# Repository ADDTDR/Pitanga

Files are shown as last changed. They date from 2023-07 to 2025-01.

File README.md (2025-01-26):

# Pitanga Project

Prototype 0.01            |  Pitanga V1 |  Pitanga V2.1a
:-------------------------:|:-------------------------:|:-------------------------:
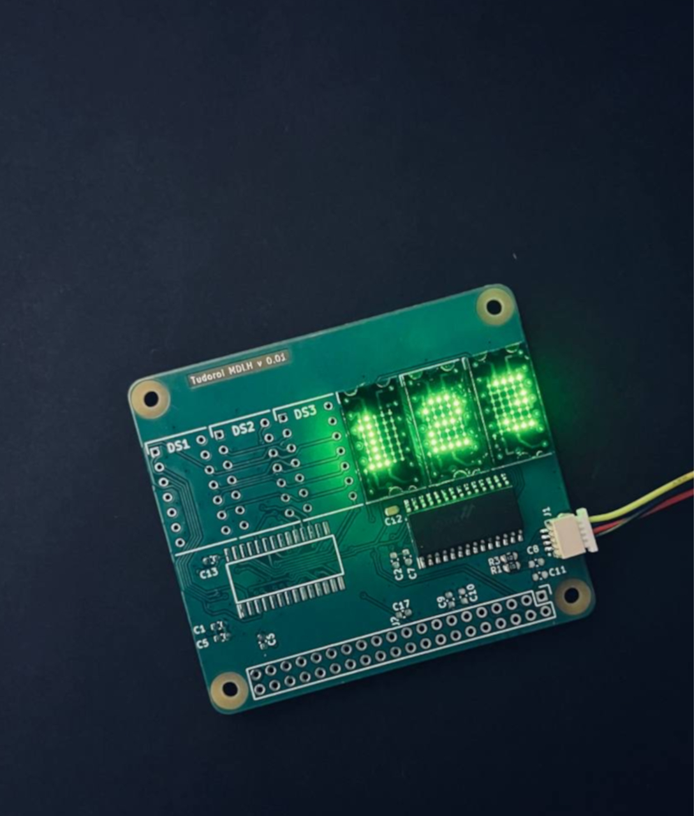
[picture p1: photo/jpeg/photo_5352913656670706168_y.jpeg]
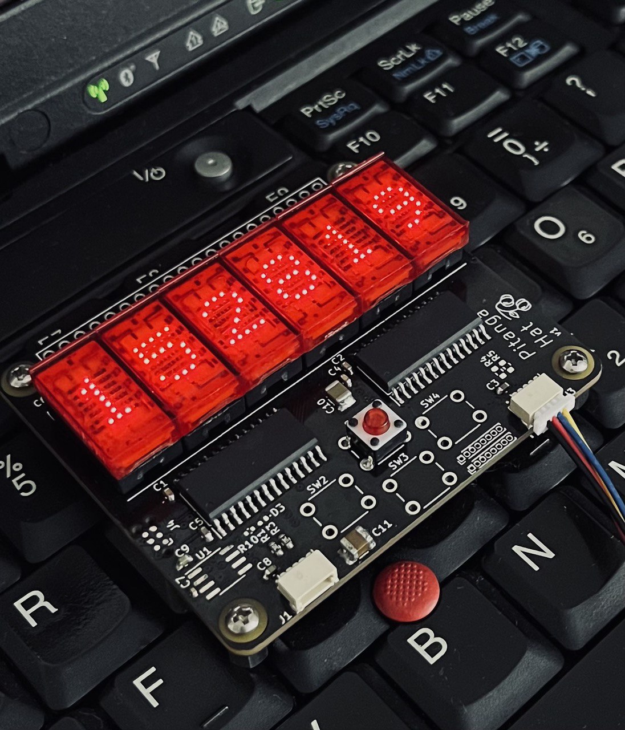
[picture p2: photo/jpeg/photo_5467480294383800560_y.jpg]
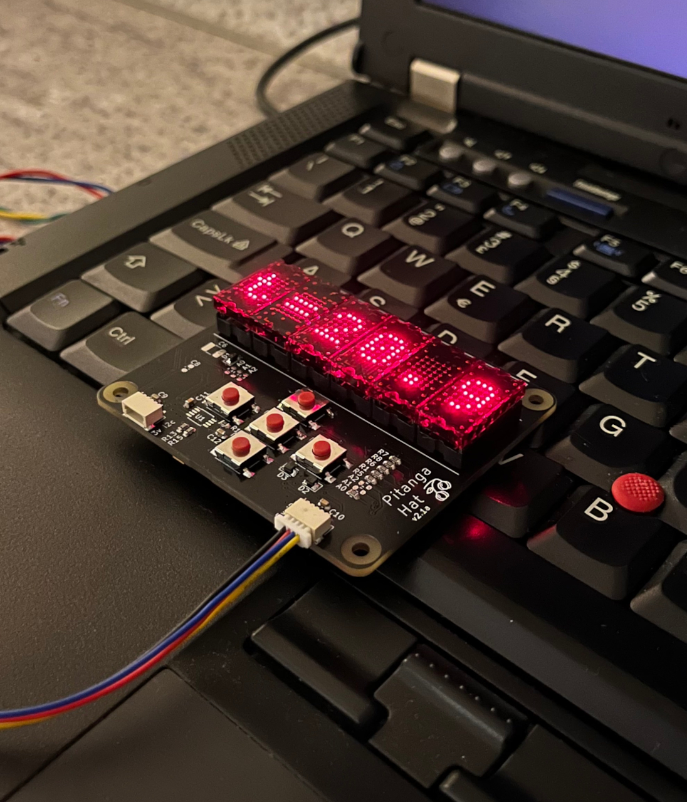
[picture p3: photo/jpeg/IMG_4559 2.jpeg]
  |    | 

<!-- # Prototype A 
```LTP-305G```
![Alt text](photo/jpeg/photo_5352913656670706168_y.jpeg)
![Alt text](photo/jpeg/photo_5352913656670706159_y.jpeg) 
# First version 
```ALS340A1 installed``` 
![Alt text](<photo/jpeg/IMG_4408 2.jpeg>)
![Alt text](<photo/jpeg/IMG_4409 2.jpeg>)
![Alt text](<photo/jpeg/IMG_4431 2.jpeg>)
Als340A1 and ALS340A
![Alt text](<photo/jpeg/IMG_4410 2.jpeg>)
ALS340A, ALS230A1, LTP305R, LTP305G
![Alt text](<photo/jpeg/IMG_4414 2.jpeg>)
ALS340A1
![Alt text](<photo/jpeg/IMG_4426 2.jpeg>)
# Version 2.1a
```LTP 305R```
![Alt text](<photo/jpeg/IMG_4559 2.jpeg>) -->

## 3D
![alt text](PitangaBlender/render/render.gif)

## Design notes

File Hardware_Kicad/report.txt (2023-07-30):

Changed footprint DS1 from 'LTP-305G:DIPS762W50P254L1850H400Q14N' to 'LTP-305G:DIPS762W50P254L1850H400Q14N': : OK

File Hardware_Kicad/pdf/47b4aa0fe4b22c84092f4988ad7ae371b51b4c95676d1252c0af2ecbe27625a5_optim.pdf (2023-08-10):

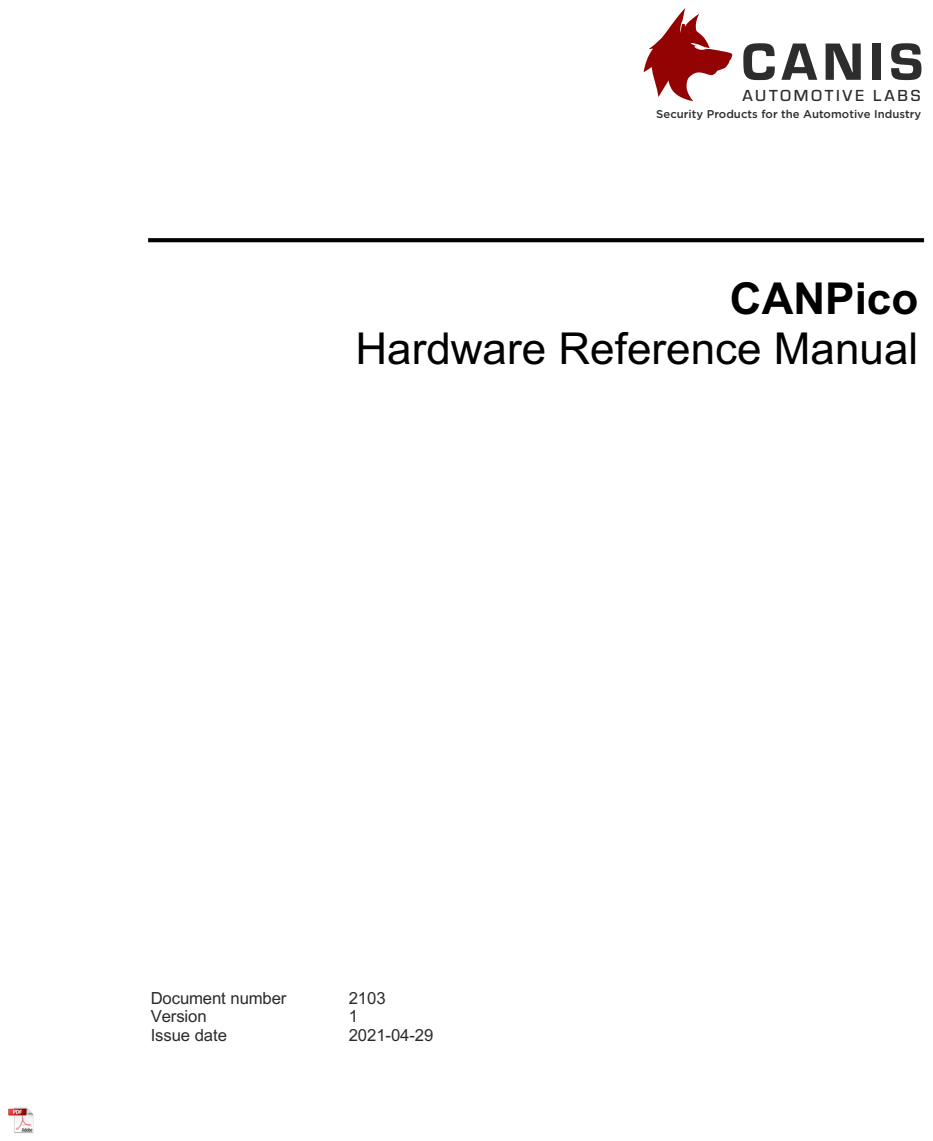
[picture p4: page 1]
CANIS; AUTOMOTIVE LABS; CANPico; Document number; Version; Issue date

Security Products for the Automotive Industry

Hardware Reference Manual

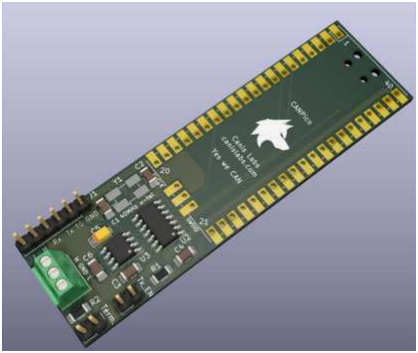
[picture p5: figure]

Copyright © 2021 Canis Automotive Labs Ltd. | 2 / 8

## 1 Introduction

The CANPico is a ‘sock’ board designed to connect a Raspberry Pi Pico board to a CAN bus. A Pico board is soldered down on to the upper area of the board and the lower area of the board contains the CAN connectors.

CAN bus is a protocol used in many applications, from trucks to buses to aircraft to agricultural equipment to medical devices to construction equipment and even spacecraft but its most common use is in cars.

WARNING. Connecting the CANPico directly to a vehicle CAN bus comes with risk and should not be undertaken without understanding this risk. Grounding a vehicle chassis through the USB port of a Pico connected to a laptop, PC or USB hub powered from the mains may cause permanent damage to the vehicle’s electronics and/or the Raspberry Pi Pico and devices it is connected to. The CAN transceiver will tolerate a ground potential difference (“ground offset”) of between -2V/+7V. Connecting pin 2 of the screw terminal to the target system’s ground will establish a common ground reference. The CAN bus must be properly terminated (with 120W resistors at either end). If the CAN bus is already terminated then the termination jumper on the CANPico should not be closed. In addition, causing disruption to a vehicle’s CAN bus traffic may be interpreted by the vehicle fault management systems as a hardware fault and cause the vehicle to permanently shut down CAN communications with consequent loss of functionality.

The CANPico has the following features:

- Microchip MCP2517/18FD CAN controller
- Microchip MCP2562FD CAN transceiver
- Jumper header to enable a 120W CAN bus termination resistor
- Jumper header to enable the CAN TX line to the transceiver¹
- Screw terminal connector to CAN bus
- CAN controller interrupt and Start-of-Frame inputs to GPIO pins
- Direct access via GPIO pins to the CAN transceiver TX and RX pins
- Test instrument header (for an oscilloscope or logic analyzer)

The features are described in more detail in the following sections. Appendix A contains the CANPico schematics.

1 Normally connected, removed to prevent software from transmitting on the CAN bus

## 2 CAN controller

The CAN controller used in the CANPico is the Microchip MCP2518FD (or in some cases the older MCP2517FD). The MCP2517/18FD is driven via SPI:

The CAN controller is clocked by a 40MHz crystal and the SPI clock from the RP2040 on the Pico can go up to 18.5MHz. More details on the SPI interface can be found in section 4 of the CAN controller datasheet (available from Microchip).

The controller can be programmed to generate an interrupt (level sensitive, active low) and this is routed to a GPIO pin on the Pico. In addition, a start-of-frame (SOF) signal is routed to another GPIO pin on the Pico, to allow timestamps in the controller for SOF to be correlated with a timer on the Pico (by latching a freerunning counter at the rising edge of the SOF signal).

The SOF signal is multiplexed with a clock signal and on power-on-reset the line is clocked at 4MHz until software re-purposes it to SOF.

## 3 CAN physical layer

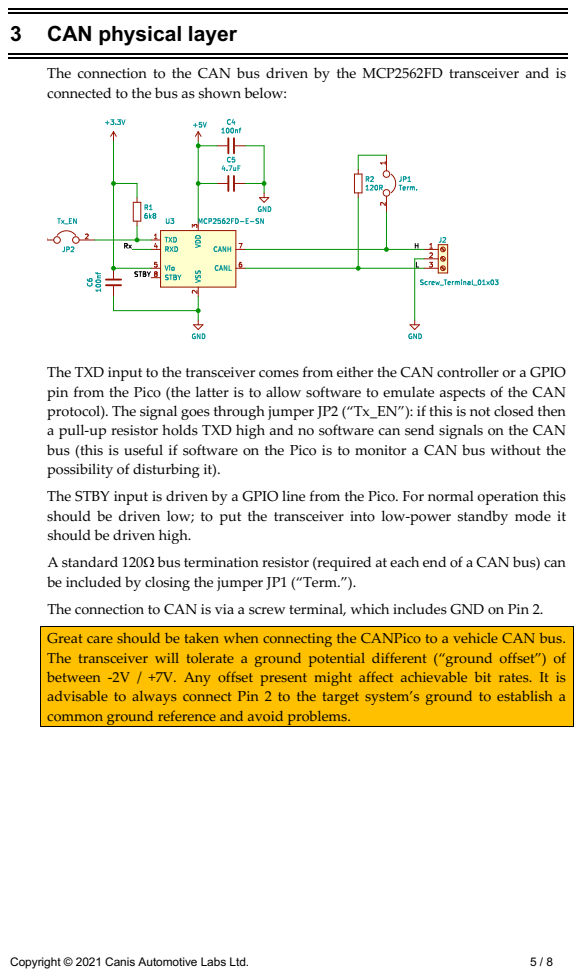
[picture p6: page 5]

The connection to the CAN bus driven by the MCP2562FD transceiver and is
connected to the bus as shown below:

The TXD input to the transceiver comes from either the CAN controller or a GPIO
pin from the Pico (the latter is to allow software to emulate aspects of the CAN
protocol). The signal goes through jumper JP2 (“Tx_EN”): if this is not closed then
a pull-up resistor holds TXD high and no software can send signals on the CAN
bus (this is useful if software on the Pico is to monitor a CAN bus without the
possibility of disturbing it).
The STBY input is driven by a GPIO line from the Pico. For normal operation this
should be driven low; to put the transceiver into low-power standby mode it
should be driven high.
A standard 120W bus termination resistor (required at each end of a CAN bus) can
be included by closing the jumper JP1 (“Term.”).
The connection to CAN is via a screw terminal, which includes GND on Pin 2.

Great care should be taken when connecting the CANPico to a vehicle CAN bus.
The transceiver will tolerate a ground potential different (“ground offset”) of
between -2V / +7V. Any offset present might affect achievable bit rates. It is
advisable to always connect Pin 2 to the target system’s ground to establish a
common ground reference and avoid problems.

## 4 Raspberry Pi Pico connections

The interface between the CANPico and the Raspberry Pi Pico is shown below:

The Pico should be soldered to the CANPico at the 13 pins shown in the schematic above. The Pico has castellated (“half moon”) edges to support this, allowing headers to be soldered into the holes if an additional Pico-compatible board is to be connected. The Pico SPI1 interface²
is used to connect to the CANPico, leaving SPI0 free to connect to other boards.

The TRIG pin (GPIO2) connects to the test instrument header. The intention is that software can be used to evaluate conditions (e.g. receiving a CAN frame with a specific ID or payload) that will trigger a logic analyzer or oscilloscope to show what was happening on the CAN line around the event.

The STBY pin (GPIO3) is used to switch the CAN transceiver between standby and normal mode.

The SOF pin (GPIO4) is wired to the CLK0/SOF pin of the CAN transceiver. On power-up this is a 4MHz clock until software re-purposes the input. If an edgesensitive SOF interrupt is required it will be important to initialize the CAN controller over SPI before enabling interrupts on GPIO4.

The Tx and Rx pins (GPIO22 and GPIO21) are wired to the CAN transceiver to allow direct software control (e.g. bit-banging the CAN protocol). This pin assignment is compatible with the CANHack pin assignment. If the Tx pin is driven by software then the CAN controller must be put into open drain mode output mode before the GPIO22 is enabled as an output (this prevents both the CAN controller and software directly driving the same line).

2 Note that the chip select pin CSn is to be driven by software (the hardware chip select included in the RP2040 SPI interface is not capable of driving the MCP2517/18FD SPI interface)

## 5 Test instrument header

A test instrument header is included to allow a logic analyzer and/or oscilloscope to monitor the CAN bus. The schematic for this header is shown below:

The TRIG pin is controlled from GPIO2 on the Pico. This can be driven by software to trigger a test instrument when certain conditions are observed. It can also be used as a general-purpose debugging pin (e.g. for measuring the execution time of sections code code).

The Rx pin is connected to the CAN transceiver’s RXD pin. Typically this would be an input to a logic analyzer monitoring the CAN bus.

The Tx pin is the output of the CAN controller and GPIO22.

The H and L pins are directly connected to CAN H and CAN L bus lines. Typically these would be inputs to an oscilloscope monitoring the CAN bus.

## 6 Appendix A: Schematics

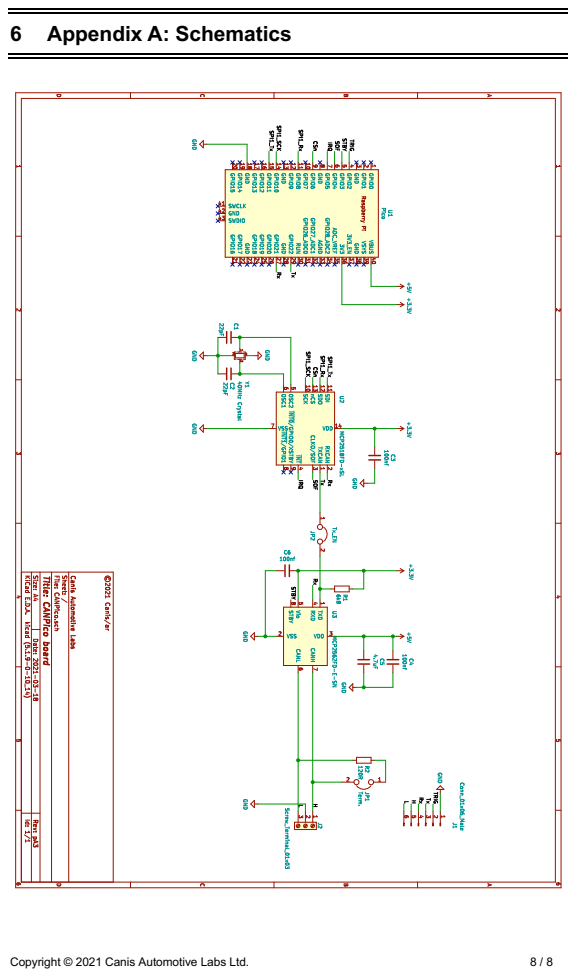
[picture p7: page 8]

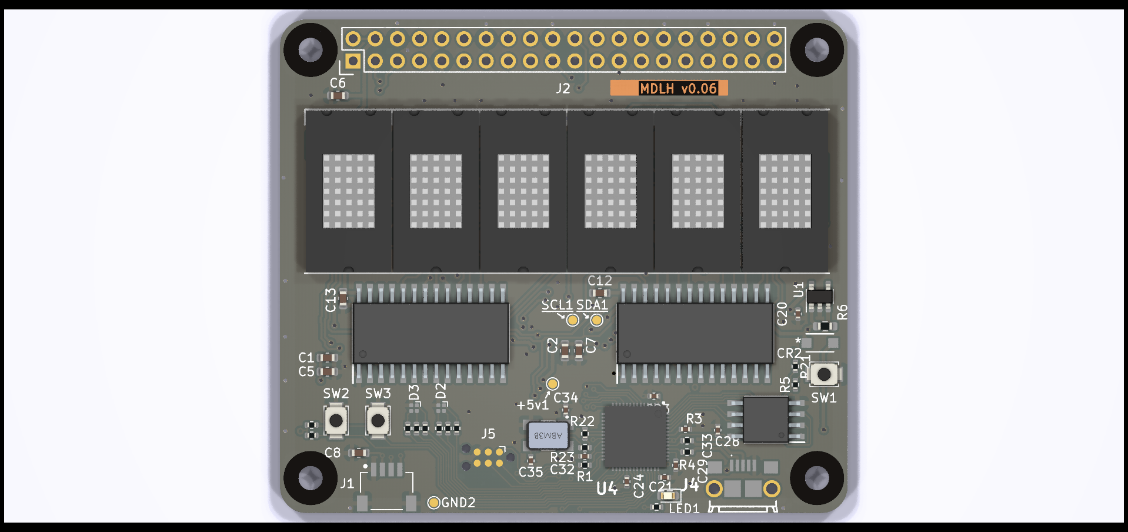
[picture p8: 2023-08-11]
Hardware_Kicad/render_images/ltp_kikad_f9.png

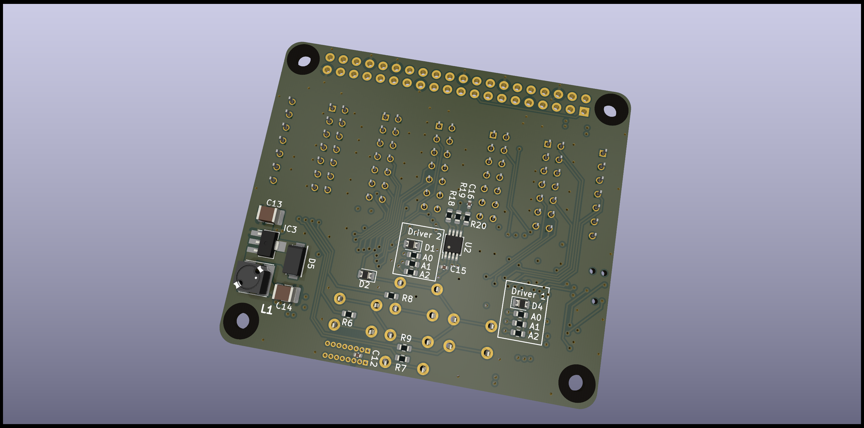
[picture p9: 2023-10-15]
Hardware_Kicad/render_images/Pitanga/pitanga_v1_back.png

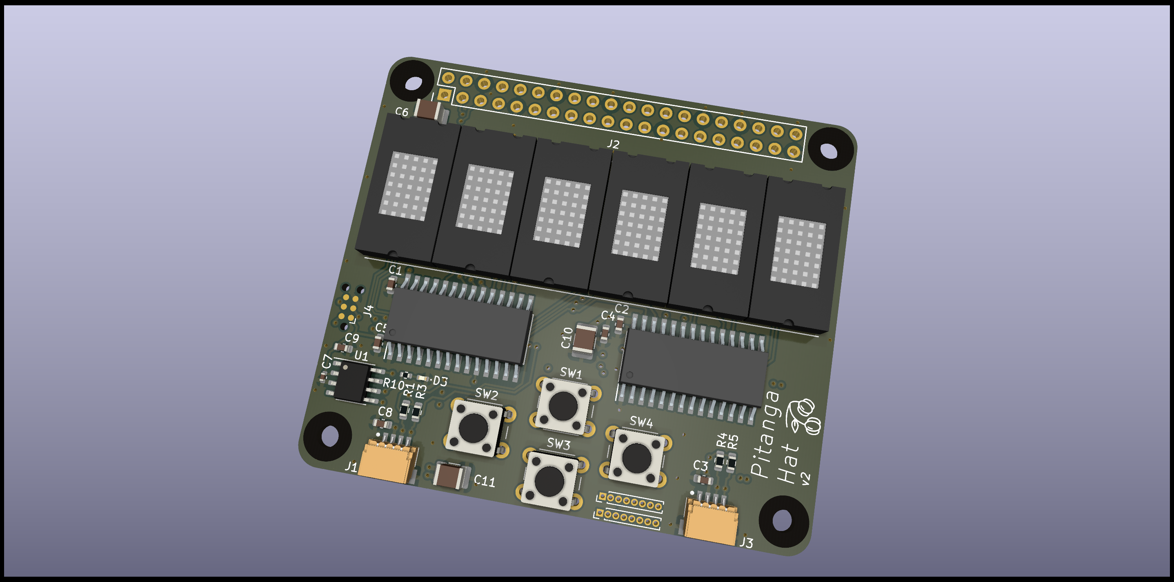
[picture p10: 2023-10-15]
Hardware_Kicad/render_images/Pitanga/pitanga_v1_front.png

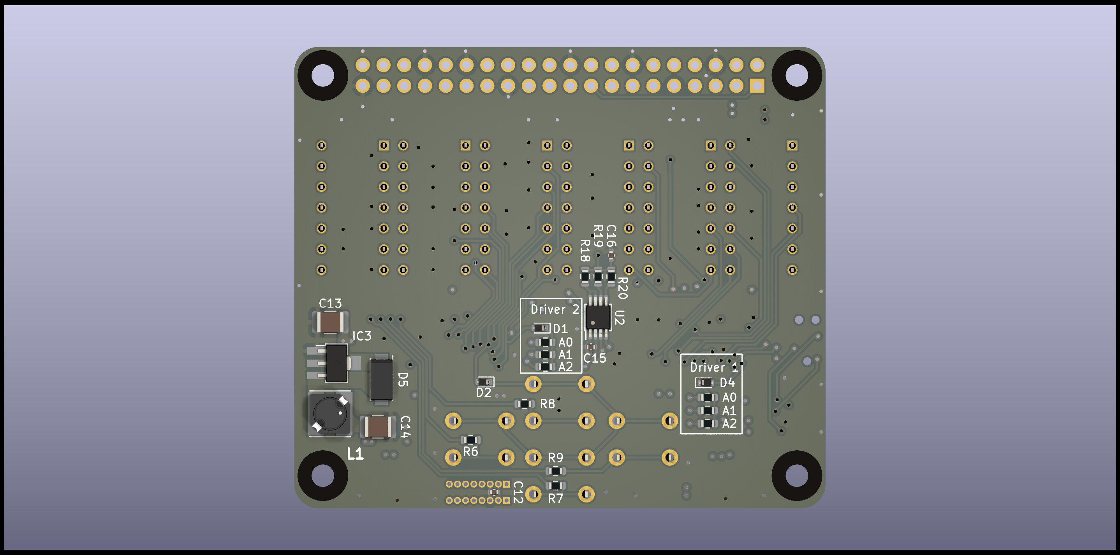
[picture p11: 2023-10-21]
Hardware_Kicad/render_images/Pitanga/pitanga_v2_back.png

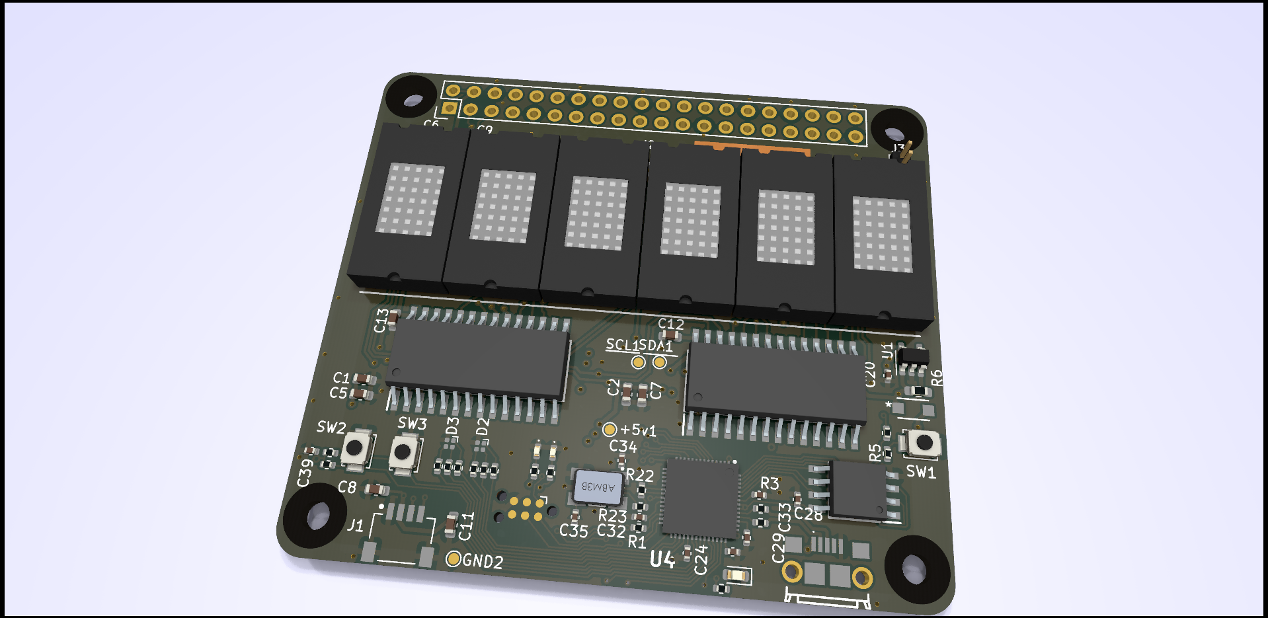
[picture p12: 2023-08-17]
Hardware_Kicad/render_images/ltp_kikad_f10.png

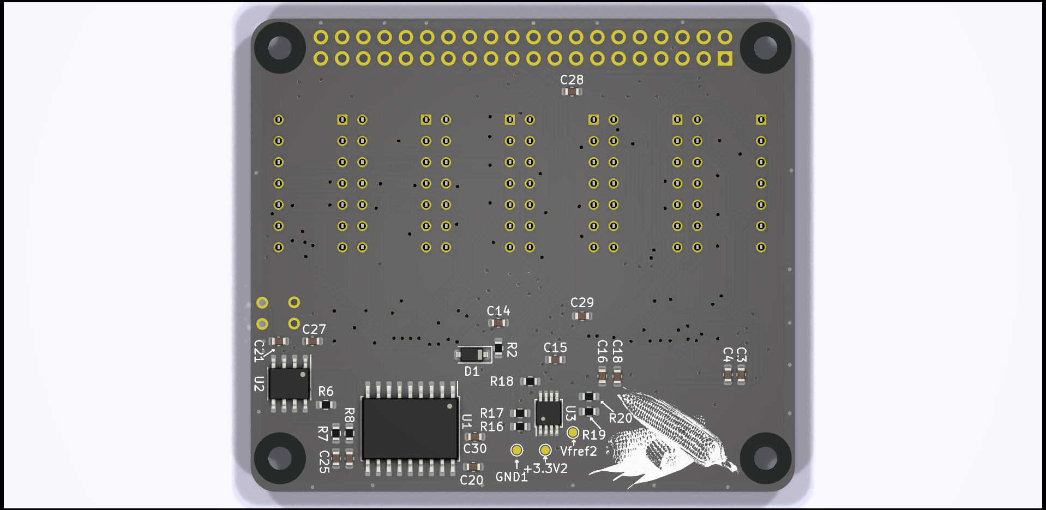
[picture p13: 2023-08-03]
Hardware_Kicad/render_images/ltp_kikad_6_b.png

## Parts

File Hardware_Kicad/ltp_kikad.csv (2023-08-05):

Source: | E:\ltp_kikad\ltp_kikad.kicad_sch
Date: | 8/4/2023 5:59:29 PM
Tool: | Eeschema 7.0.5
Generator: | C:\Program Files\KiCad\7.0\bin\scripting\plugins/bom_csv_grouped_by_value.py
Component Count: | 73
Collated Components:
Item | Qty | Reference(s) | Value | LibPart | Footprint | Datasheet | DNP | Arrow Part Number | Arrow Price/Stock | Description | Digi-Key_PN | Height | MANUFACTURER | MPN | Manufacturer | Manufacturer_Name | Manufacturer_Part_Number | Mouser Part Number | Mouser Price/Stock | STANDARD | Sim.Device | Sim.Pins
1 | 4 | +3.3v1, +5v1, GND1, GND2 | TestPoint | Connector:TestPoint | TestPoint:TestPoint_Pad_D1.0mm | ~
2 | 1 | +3.3V2 | TP3.3v | Connector:TestPoint | TestPoint:TestPoint_Pad_D1.0mm | ~
3 | 15 | C1, C2, C7, C8, C9, C10, C11, C12, C13, C14, C15, C16, C17, C18, C27 | 10uF | Device:C_Small | Capacitor_SMD:C_0603_1608Metric | ~
4 | 4 | C3, C4, C19, C22 | 4.7uF | Device:C_Small | Capacitor_SMD:C_0603_1608Metric | ~
5 | 7 | C5, C6, C20, C21, C28, C29, C30 | 0.1uF | Device:C_Small | Capacitor_SMD:C_0603_1608Metric | ~
6 | 2 | C23, C24 | 22pF | Device:C_Small | Capacitor_SMD:C_0603_1608Metric | ~
7 | 2 | C25, C26 | 560pF | Device:C_Small | Capacitor_SMD:C_0603_1608Metric | ~
8 | 1 | CAN1 | Jumper_2_Open | Jumper:Jumper_2_Open | TestPoint:TestPoint_2Pads_Pitch2.54mm_Drill0.8mm | ~
9 | 1 | D1 | 1N4148 | Device:D | Diode_SMD:D_SOD-123 | ~ |  |  |  |  |  |  |  |  |  |  |  |  |  |  | D | 1=K 2=A
10 | 6 | DS1, DS2, DS3, DS4, DS5, DS6 | LTP-305G | LTP-305G:LTP-305G | LTP-305G:DIPS762W50P254L1850H400Q14N | https://media.digikey.com/pdf/Data%20Sheets/Lite-On%20PDFs/LTP-305G.pdf |  | LTP-305G | https://www.arrow.com/en/products/ltp-305g/lite-on-technology?region=nac |  |  | 4 |  |  |  | Lite-On | LTP-305G | 859-LTP-305G | https://www.mouser.co.uk/ProductDetail/Lite-On/LTP-305G?qs=gnaPJ2cis70tTyscg55DVQ%3D%3D
11 | 2 | IC1, IC2 | SamacSys_Parts_HT16K33-28SOP | LTP305_ESP32_CLOCK-rescue:HT16K33-28SOP-SamacSys_Parts | Holtek:SOIC127P1031X264-28N | http://uk.rs-online.com/web/p/products/8850765 |  |  |  | Key-in LED Control Driver RAM I2C 28SOP Holtek HT16K33-28SOP, LED Driver 16-Segments, 5 V, 28-Pin SOP |  | 2.64 |  |  |  | Holtek | HT16K33-28SOP
12 | 1 | J1 | SM04B-SRSS-TB(LF)(SN) | SM04B-SRSS-TB_LF__SN_:SM04B-SRSS-TB(LF)(SN) | LTP-305G:JST_SM04B-SRSS-TB(LF)(SN) |  |  |  |  |  | 455-1804-1-ND |  | JST | SM04B-SRSS-TB(LF)(SN) | JST Sales America Inc. |  |  |  |  | Manufacturer recommendations
13 | 1 | J2 | RPi_GPIO | RPi_Hat:RPi_GPIO | LTP-305G:Pin_Header_Straight_2x20
14 | 1 | JP1 | Jumper_2_Bridged | Jumper:Jumper_2_Bridged | TestPoint:TestPoint_2Pads_Pitch2.54mm_Drill0.8mm | ~
15 | 1 | PWR1 | Green | Device:LED | LED_SMD:LED_0603_1608Metric_Pad1.05x0.95mm_HandSolder | ~
16 | 1 | R2 | 47k | Device:R | Resistor_SMD:R_0603_1608Metric | ~
17 | 3 | R6, R10, R15 | 4k7 | Device:R | Resistor_SMD:R_0603_1608Metric | ~
18 | 2 | R7, R8 | 100 | Device:R | Resistor_SMD:R_0603_1608Metric | ~
19 | 1 | R9 | 120 | Device:R | Resistor_SMD:R_0805_2012Metric_Pad1.20x1.40mm_HandSolder | ~
20 | 2 | R11, R12 | 0 | Device:R | Resistor_SMD:R_0603_1608Metric | ~
21 | 2 | R13, R14 | DNP | Device:R | Resistor_SMD:R_0603_1608Metric | ~
22 | 4 | R16, R17, R19, R20 | i2c | Device:R | Resistor_SMD:R_0603_1608Metric | ~
23 | 1 | R18 | 200k | Device:R | Resistor_SMD:R_0603_1608Metric | ~
24 | 1 | SCL1 | SCL | Connector:TestPoint | TestPoint:TestPoint_Pad_D1.0mm | ~
25 | 1 | SDA1 | SDA | Connector:TestPoint | TestPoint:TestPoint_Pad_D1.0mm | ~
26 | 1 | U1 | MCP2515-xSO | Interface_CAN_LIN:MCP2515-xSO | Package_SO:SOIC-18W_7.5x11.6mm_P1.27mm | http://ww1.microchip.com/downloads/en/DeviceDoc/21801e.pdf
27 | 1 | U2 | MCP2551-I-SN | Interface_CAN_LIN:MCP2551-I-SN | Package_SO:SOIC-8_3.9x4.9mm_P1.27mm | http://ww1.microchip.com/downloads/en/devicedoc/21667d.pdf
28 | 1 | U3 | PCA9306DP | Interface:PCA9306DP | Package_SO:TSSOP-8_3x3mm_P0.65mm | https://www.nxp.com/docs/en/data-sheet/PCA9306.pdf
29 | 1 | U4 | STM32F103CBTx | MCU_ST_STM32F1:STM32F103CBTx | Package_QFP:LQFP-48_7x7mm_P0.5mm | https://www.st.com/resource/en/datasheet/stm32f103cb.pdf
30 | 1 | Vfref2 | Vref2 | Connector:TestPoint | TestPoint:TestPoint_Pad_D1.0mm | ~
31 | 1 | Y1 | 16MHz | Device:Crystal | Crystal:Crystal_SMD_HC49-SD | ~

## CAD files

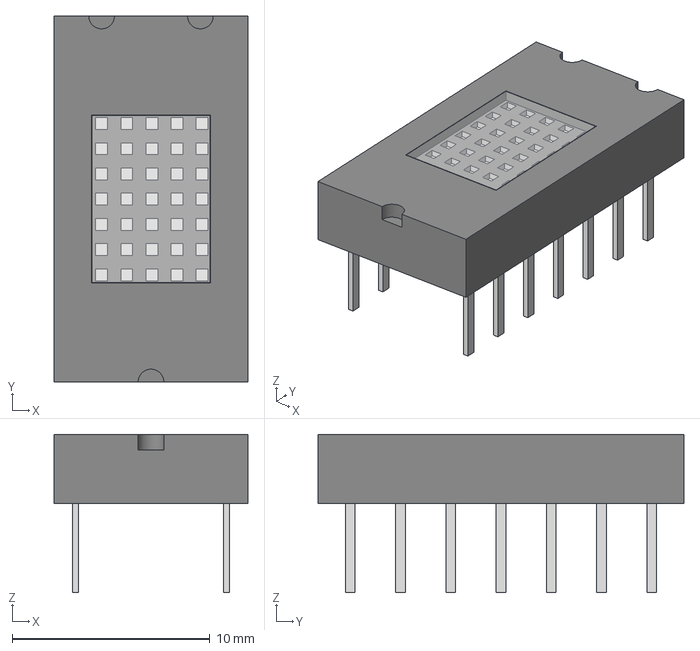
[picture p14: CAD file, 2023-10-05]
Hardware_Kicad/3dmodels/LTP-305G.stp
9.80 x 18.5 x 8.00 mm

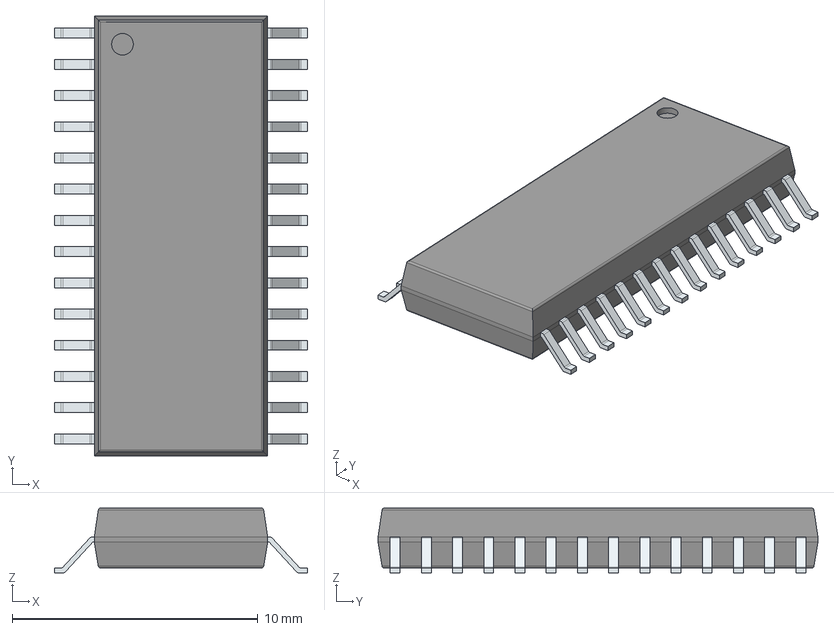
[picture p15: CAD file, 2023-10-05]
Hardware_Kicad/3dmodels/HT16K33-28SOP.stp
10.3 x 17.9 x 2.64 mm
PinsArrayLR

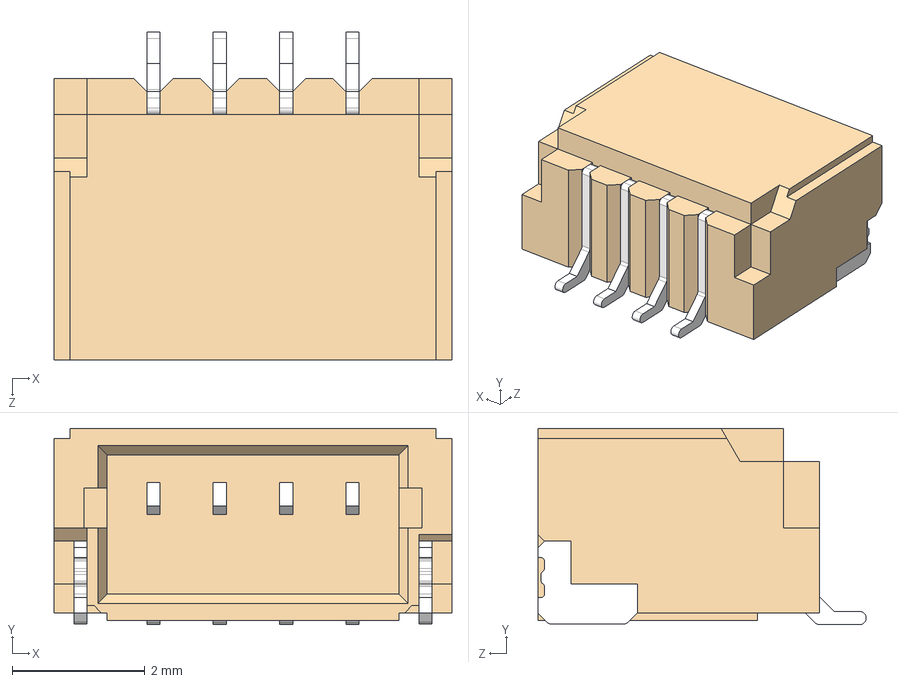
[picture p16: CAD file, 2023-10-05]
Hardware_Kicad/3dmodels/SM04B-SRSS-TB_LF__SN_.stp
6.00 x 2.96 x 4.95 mm

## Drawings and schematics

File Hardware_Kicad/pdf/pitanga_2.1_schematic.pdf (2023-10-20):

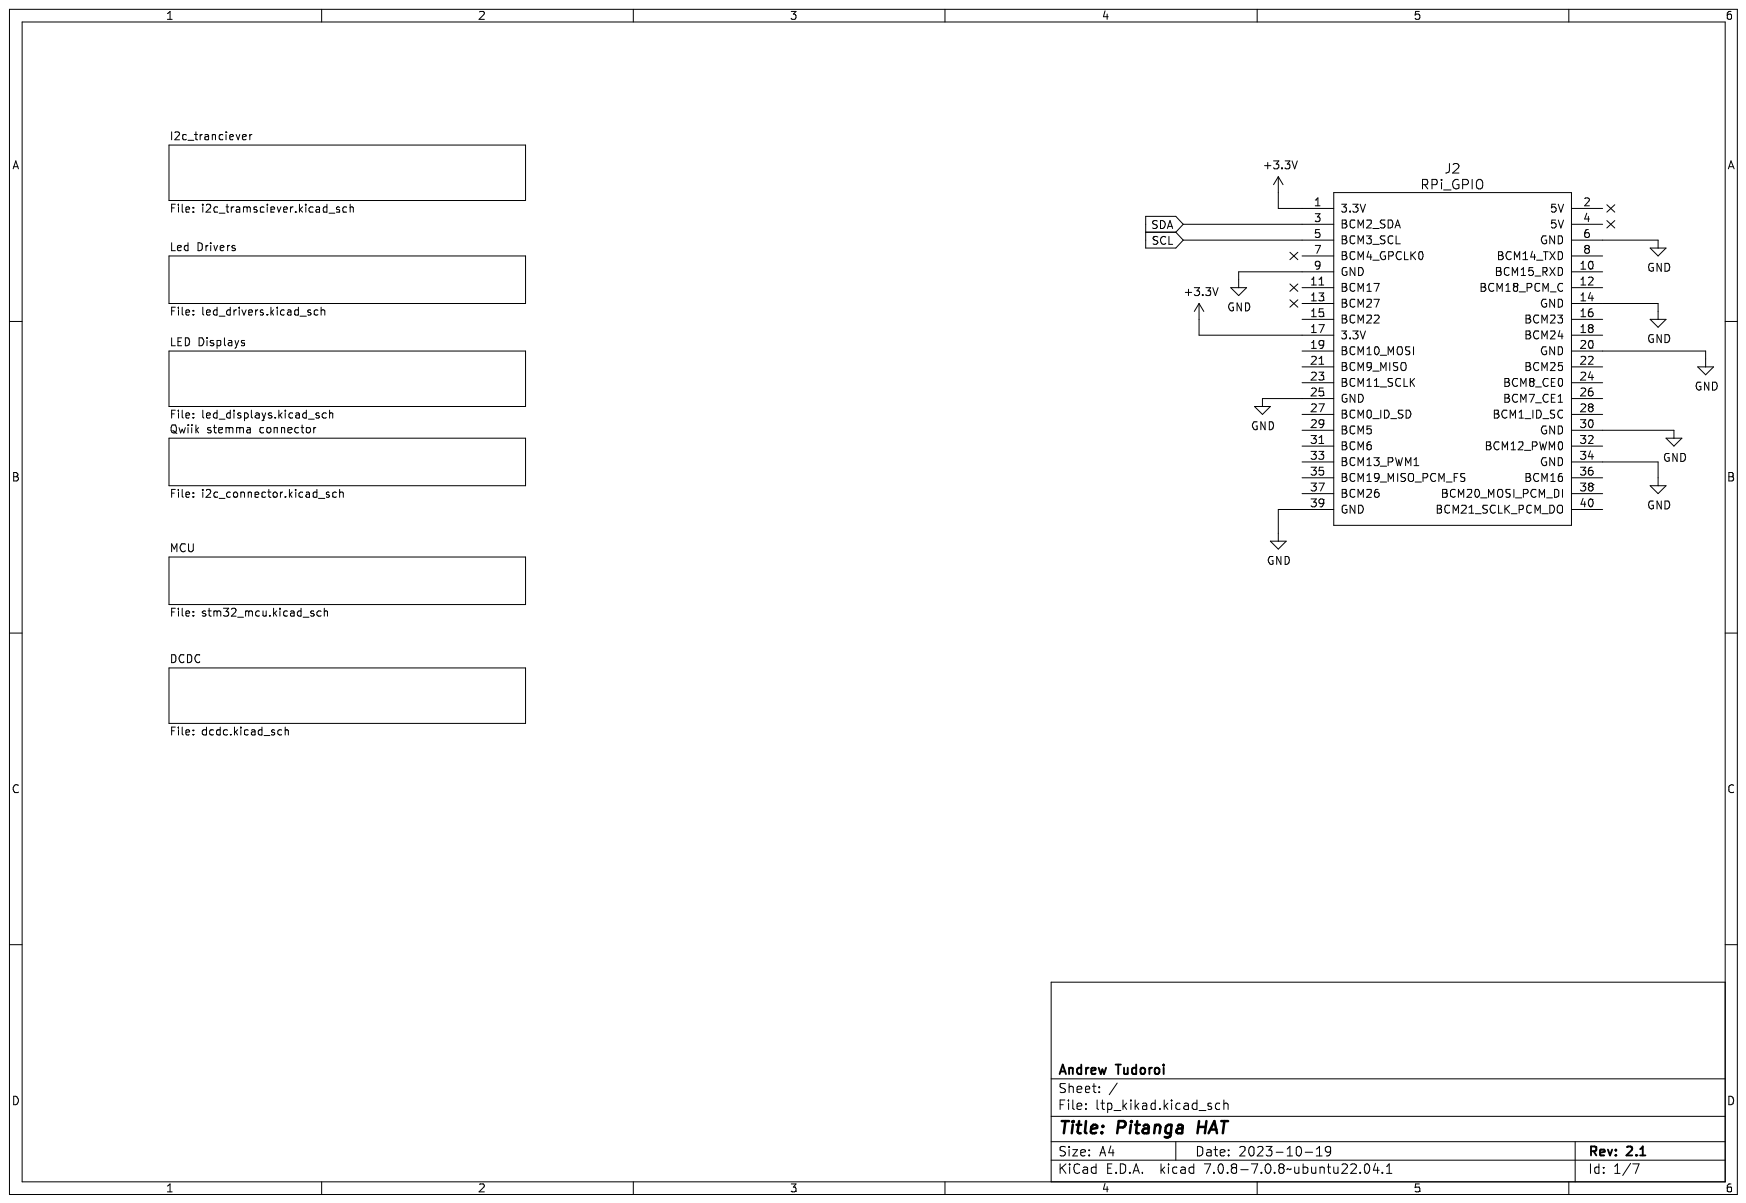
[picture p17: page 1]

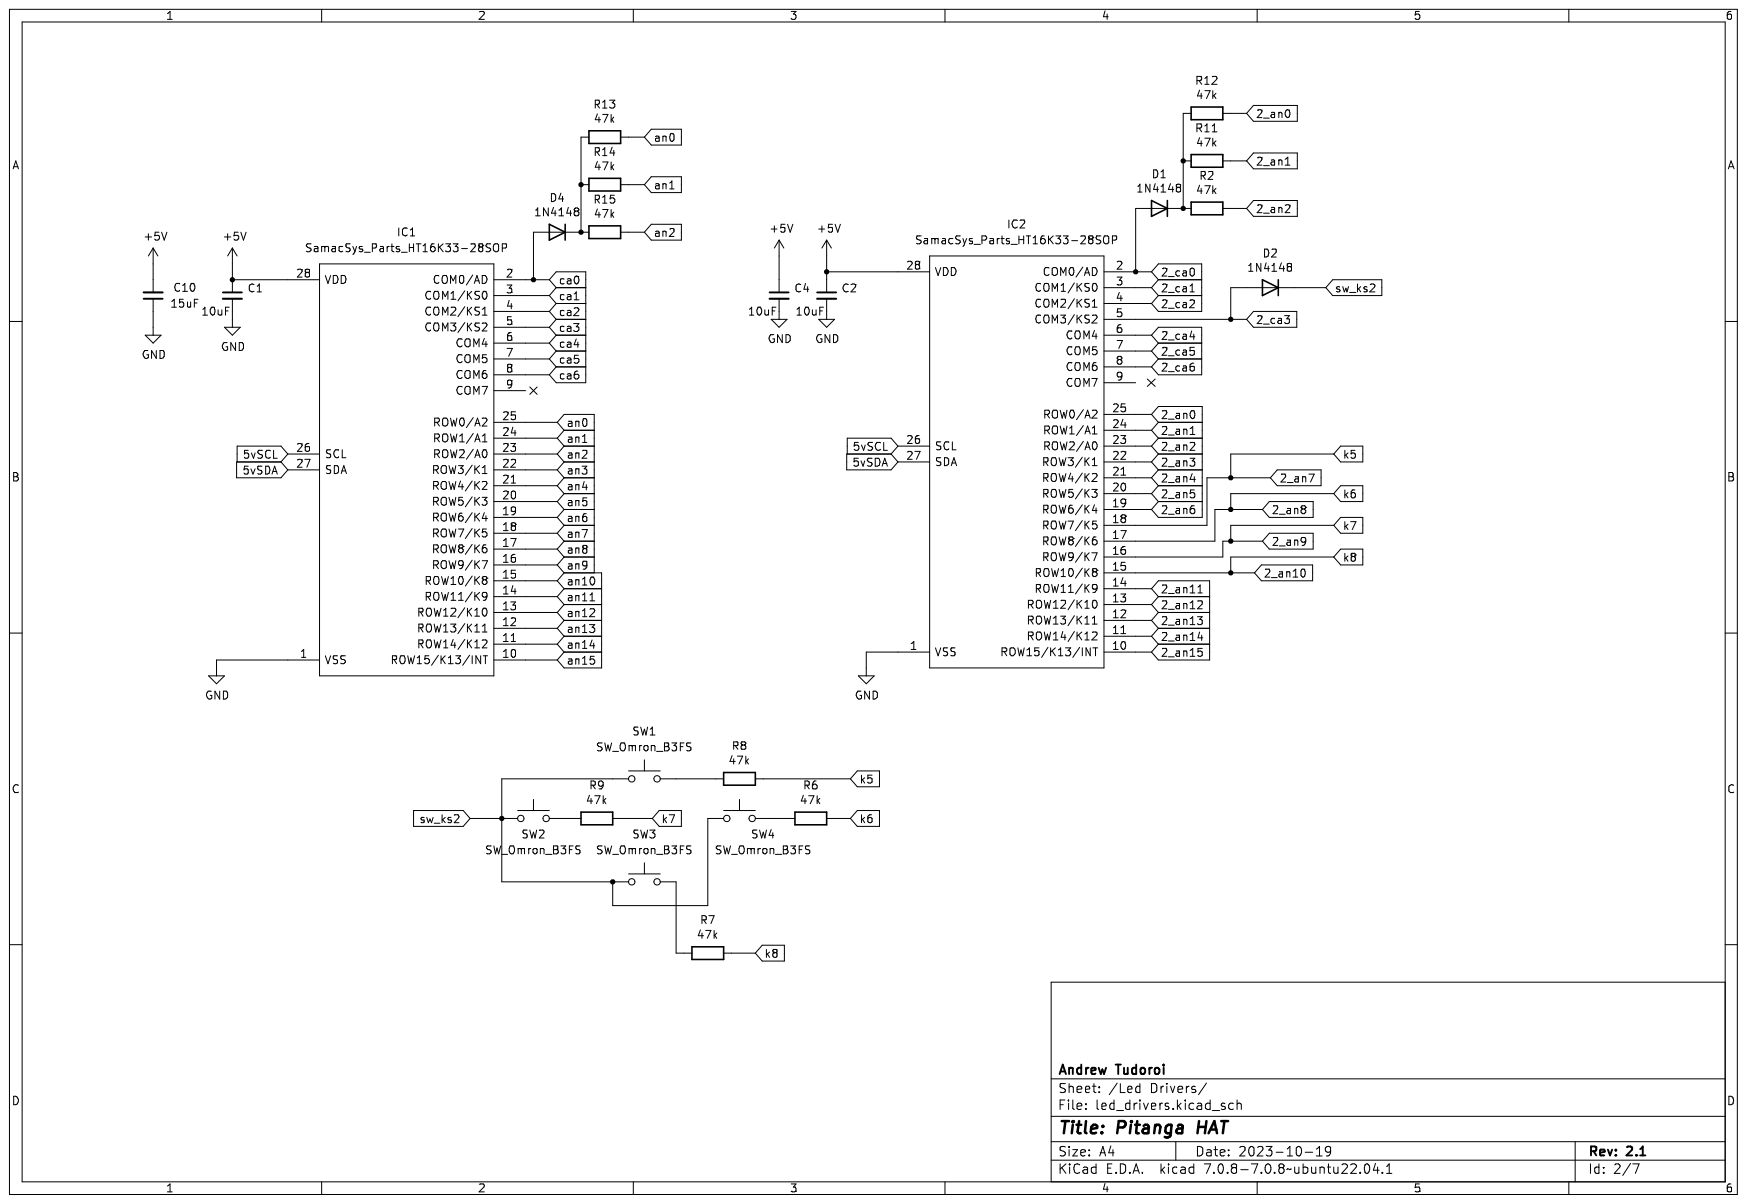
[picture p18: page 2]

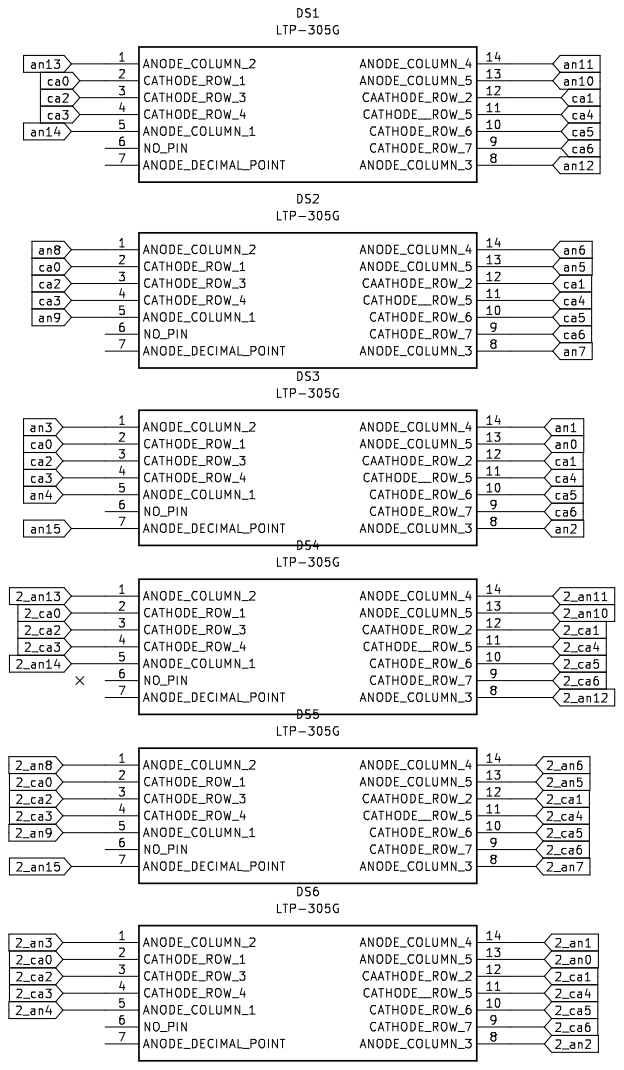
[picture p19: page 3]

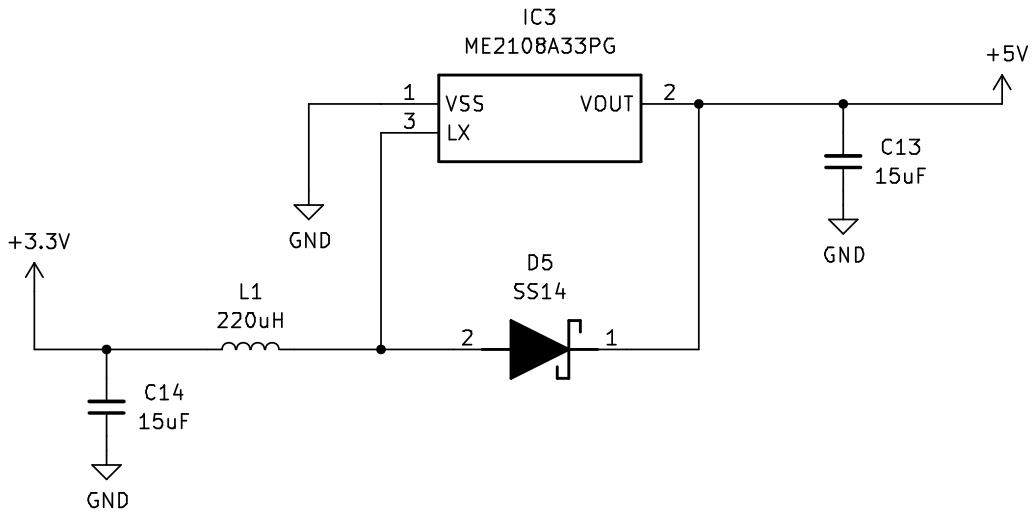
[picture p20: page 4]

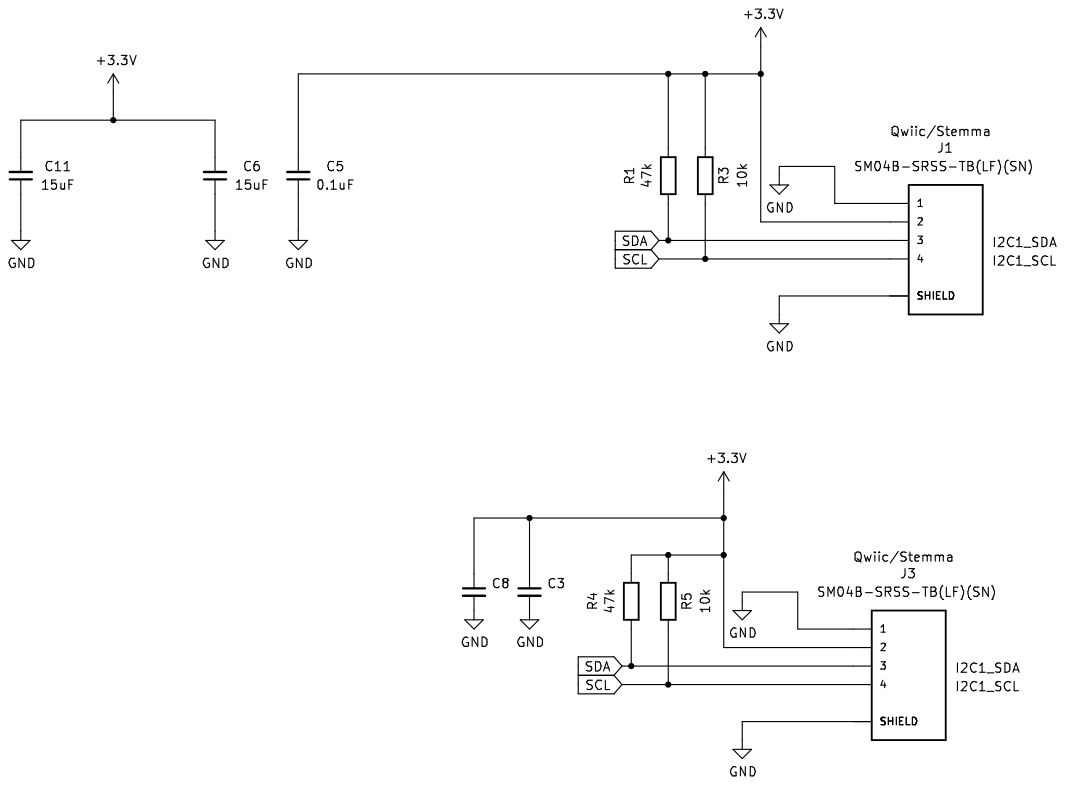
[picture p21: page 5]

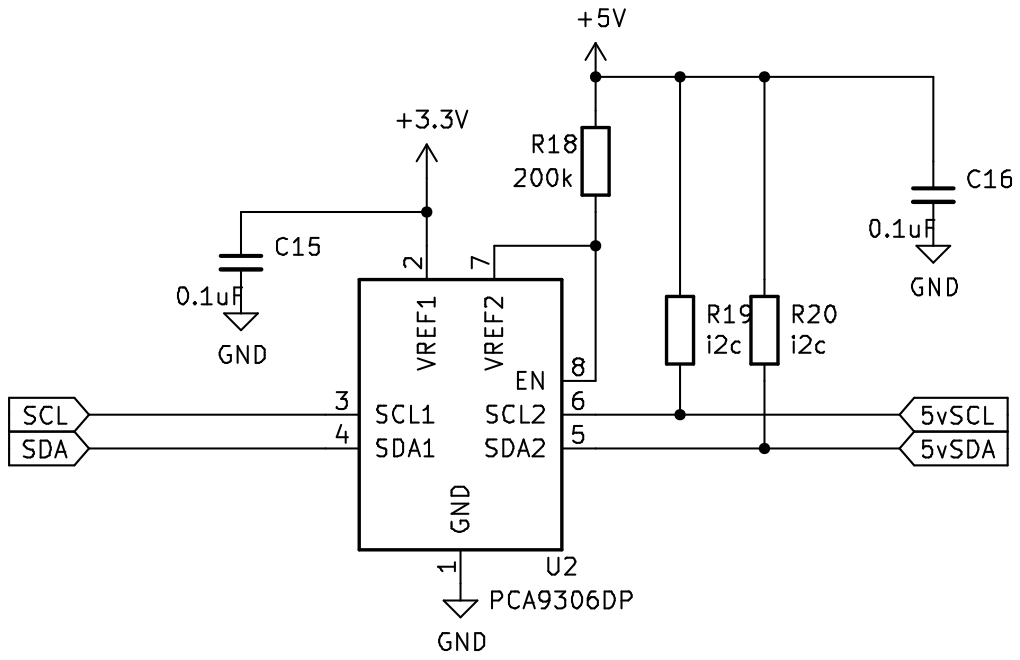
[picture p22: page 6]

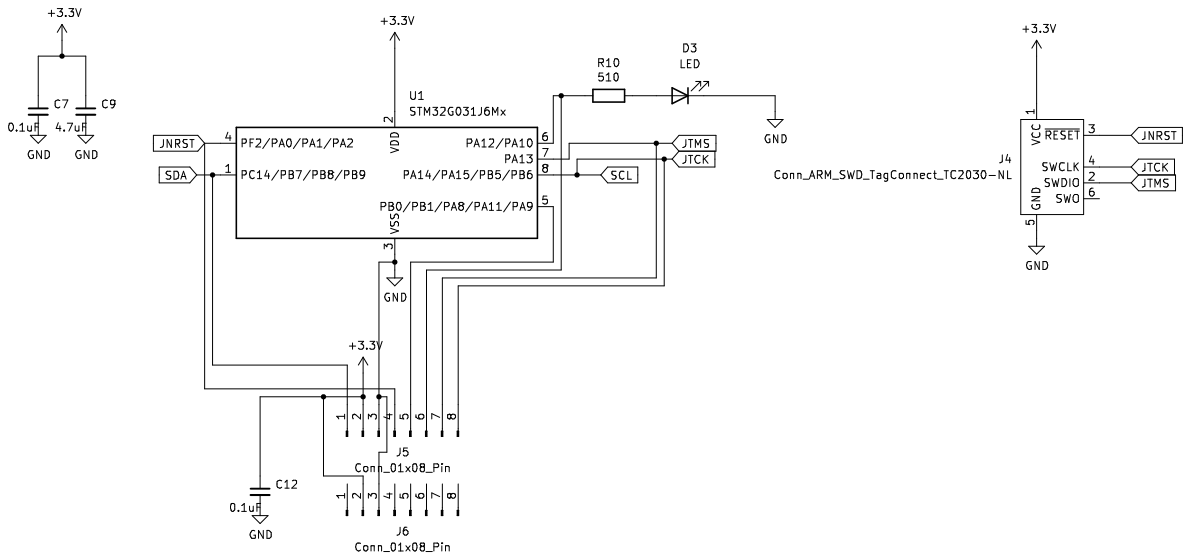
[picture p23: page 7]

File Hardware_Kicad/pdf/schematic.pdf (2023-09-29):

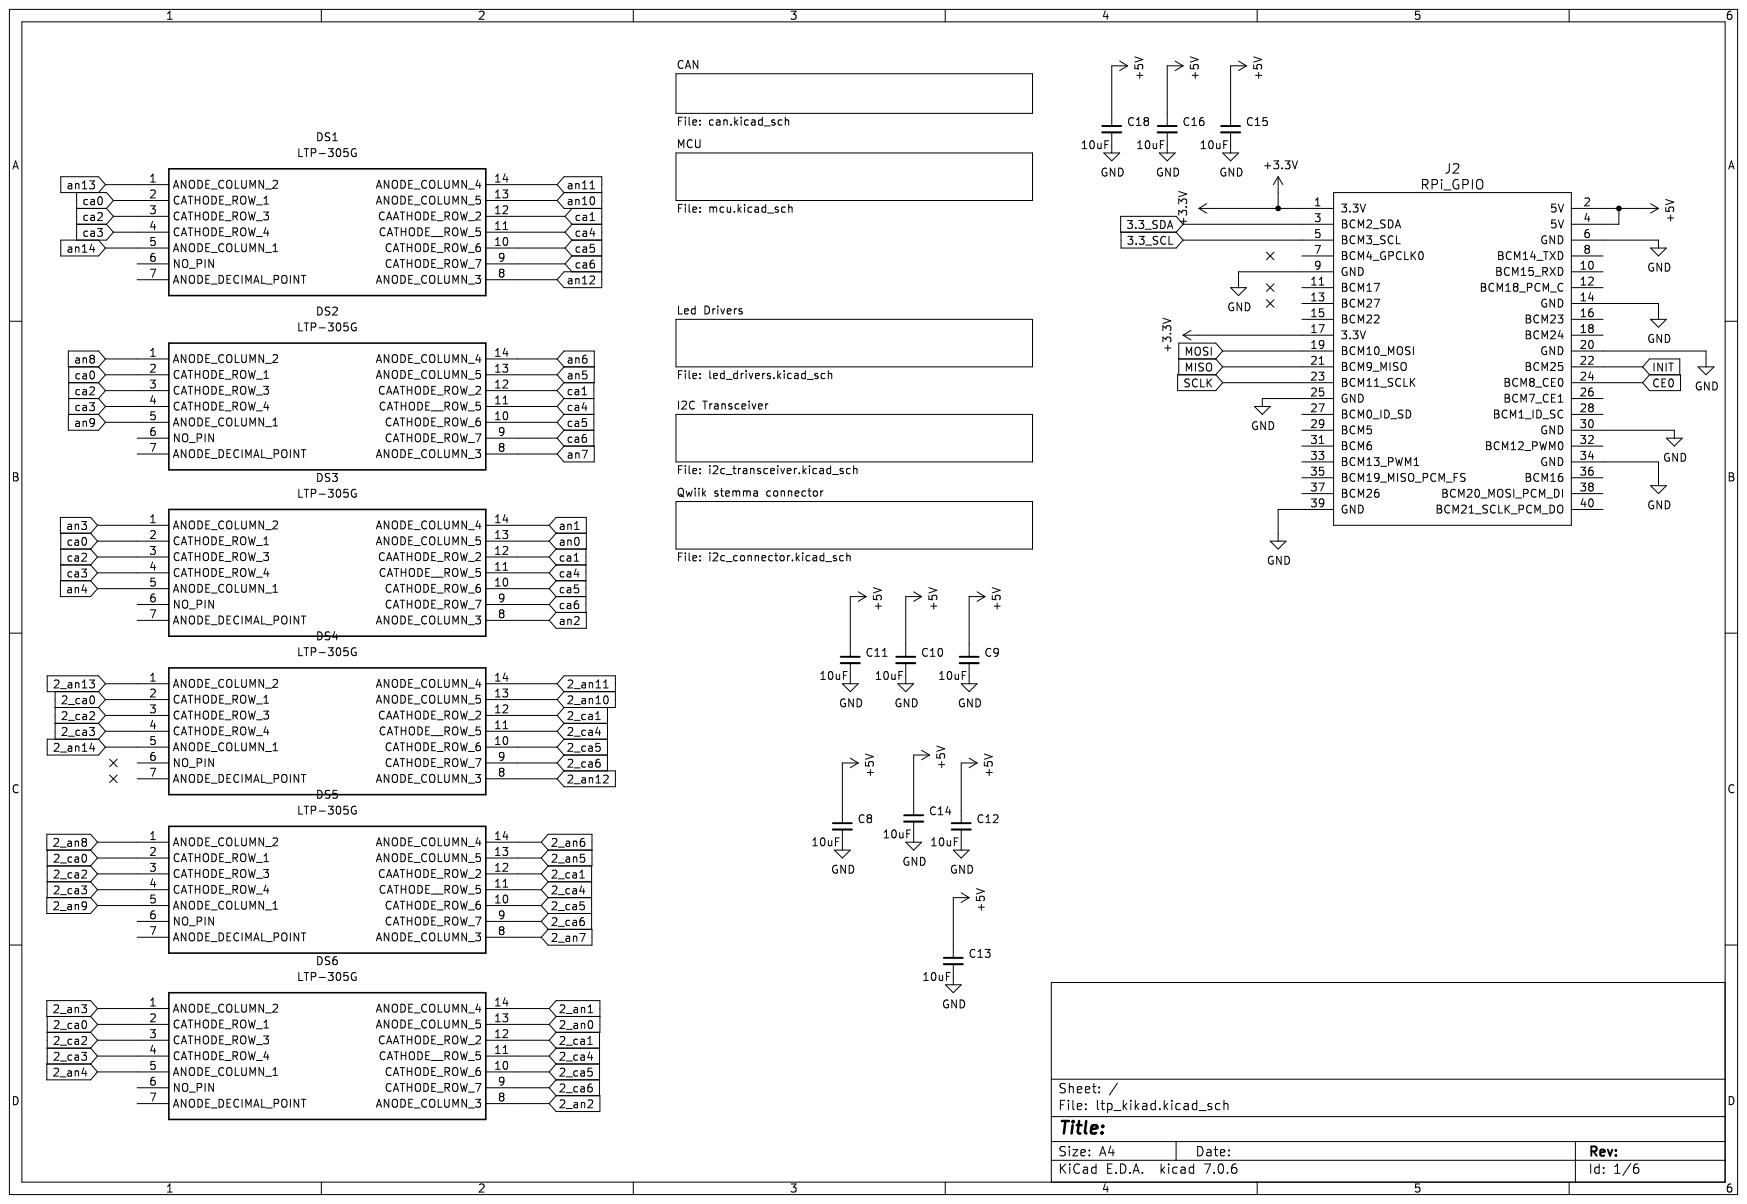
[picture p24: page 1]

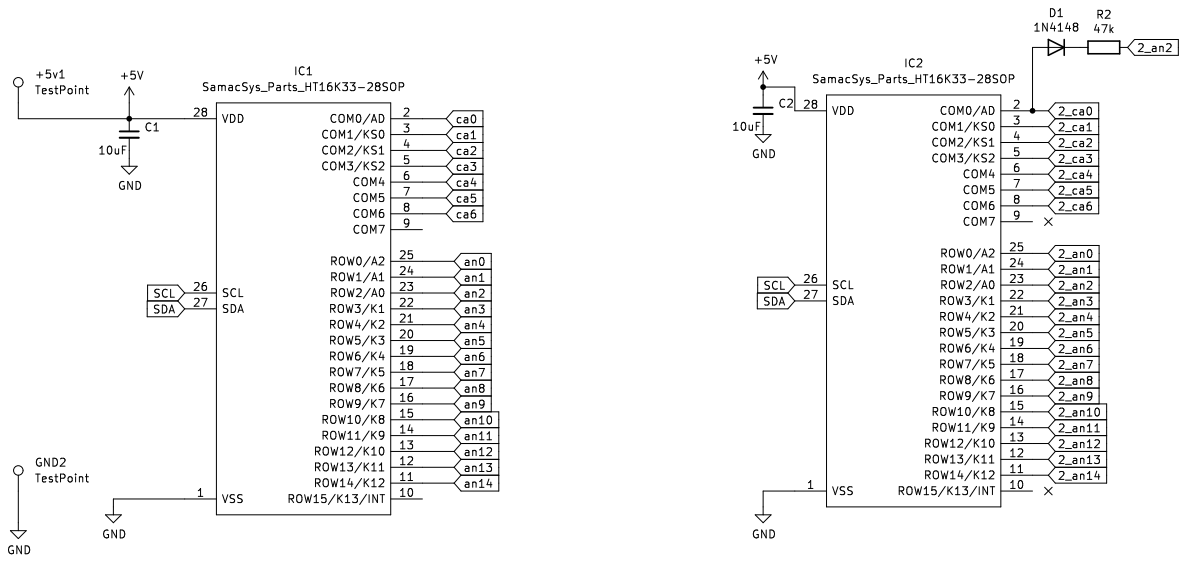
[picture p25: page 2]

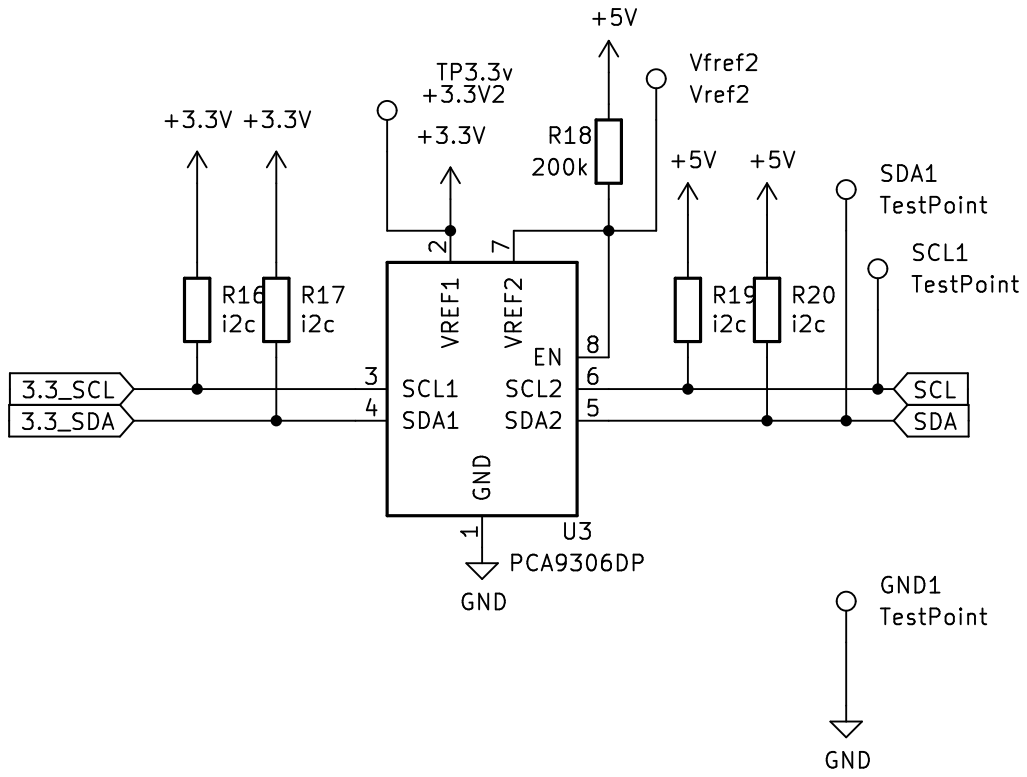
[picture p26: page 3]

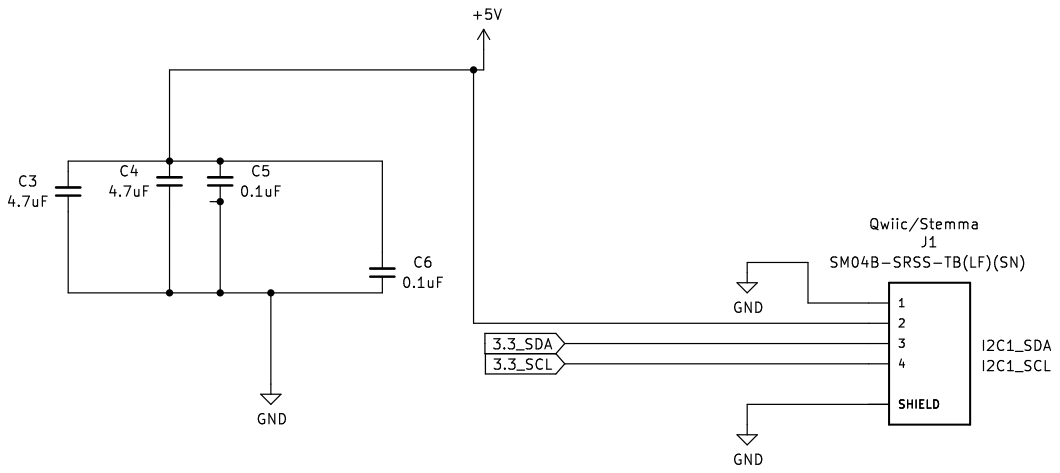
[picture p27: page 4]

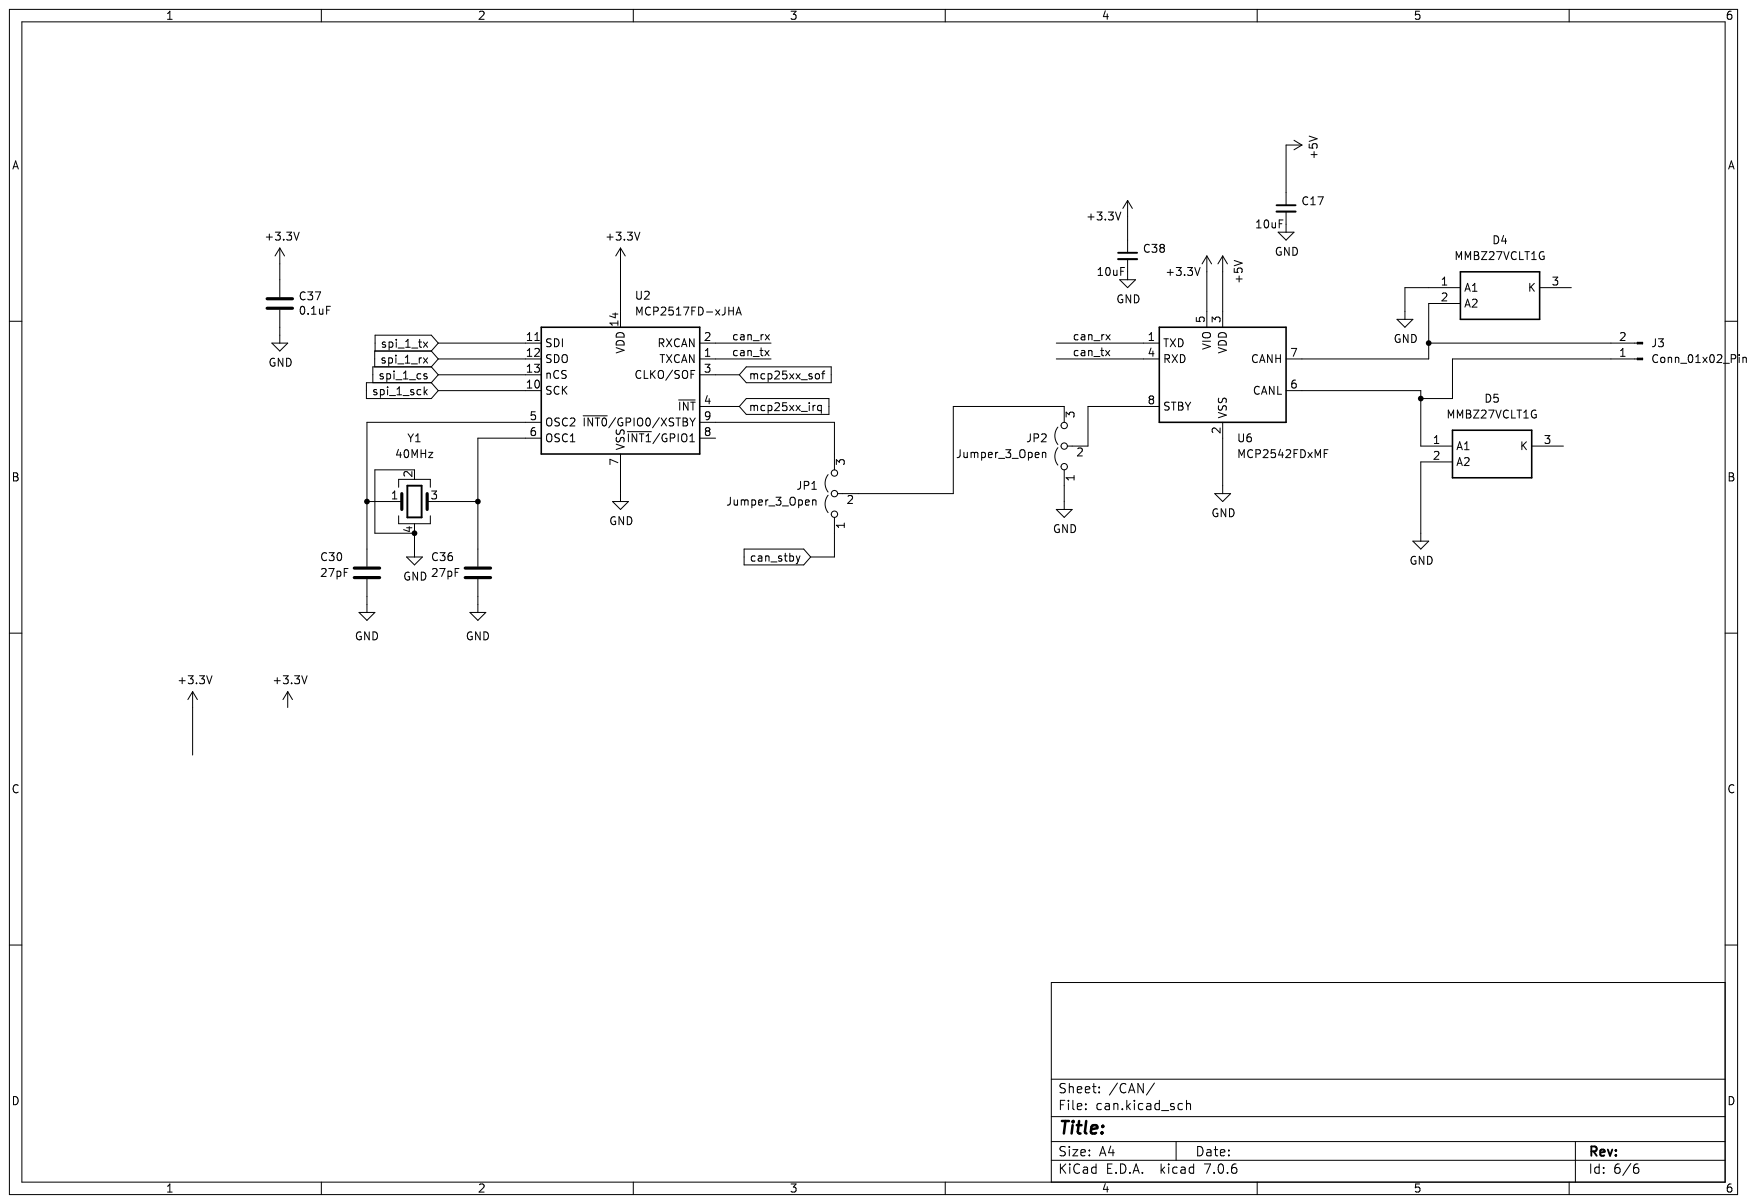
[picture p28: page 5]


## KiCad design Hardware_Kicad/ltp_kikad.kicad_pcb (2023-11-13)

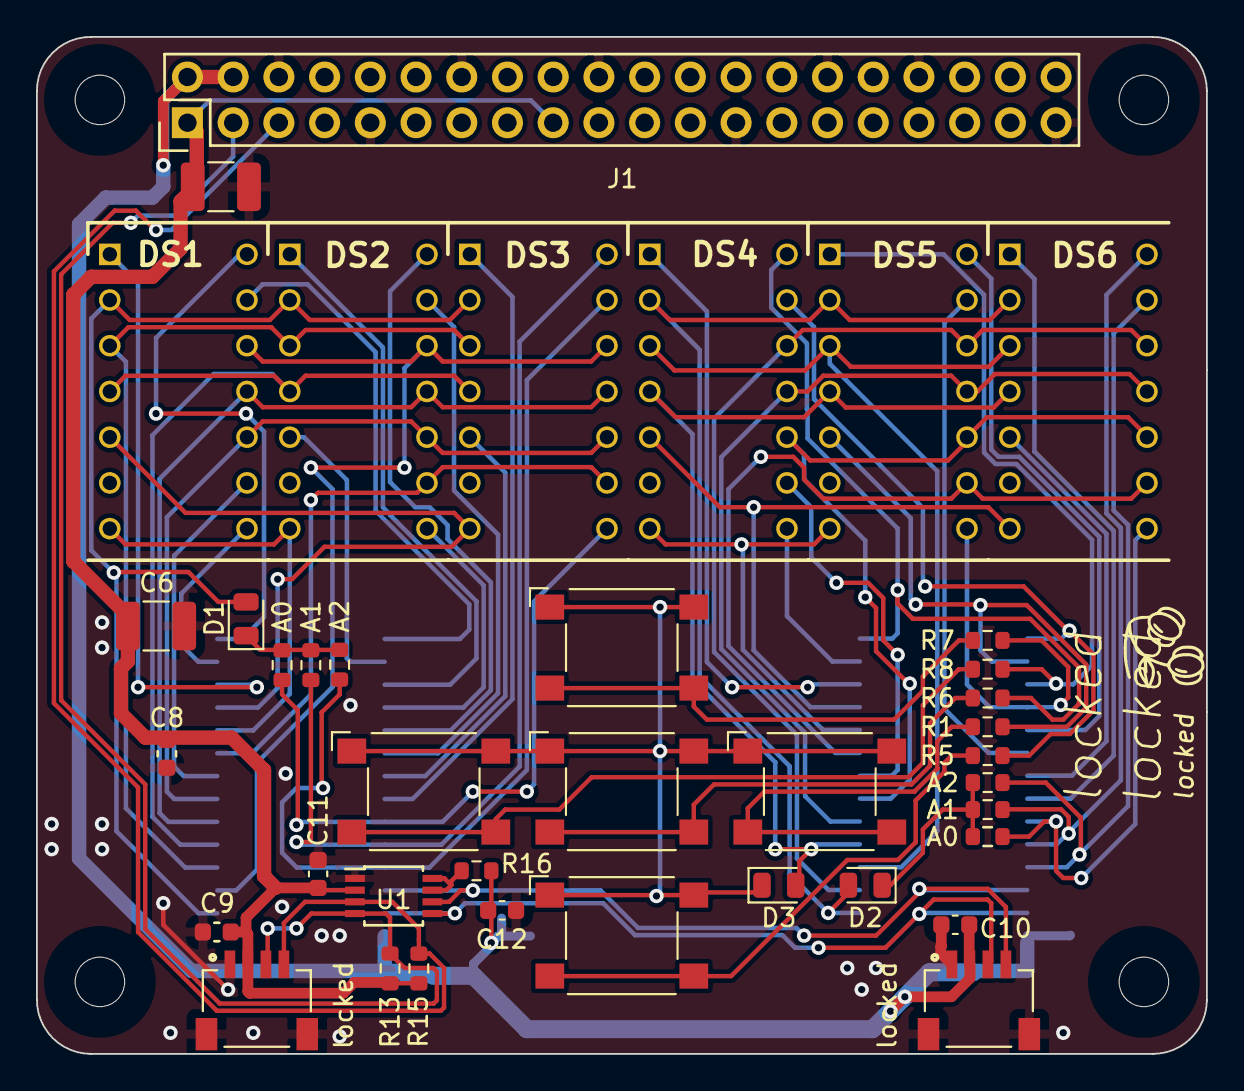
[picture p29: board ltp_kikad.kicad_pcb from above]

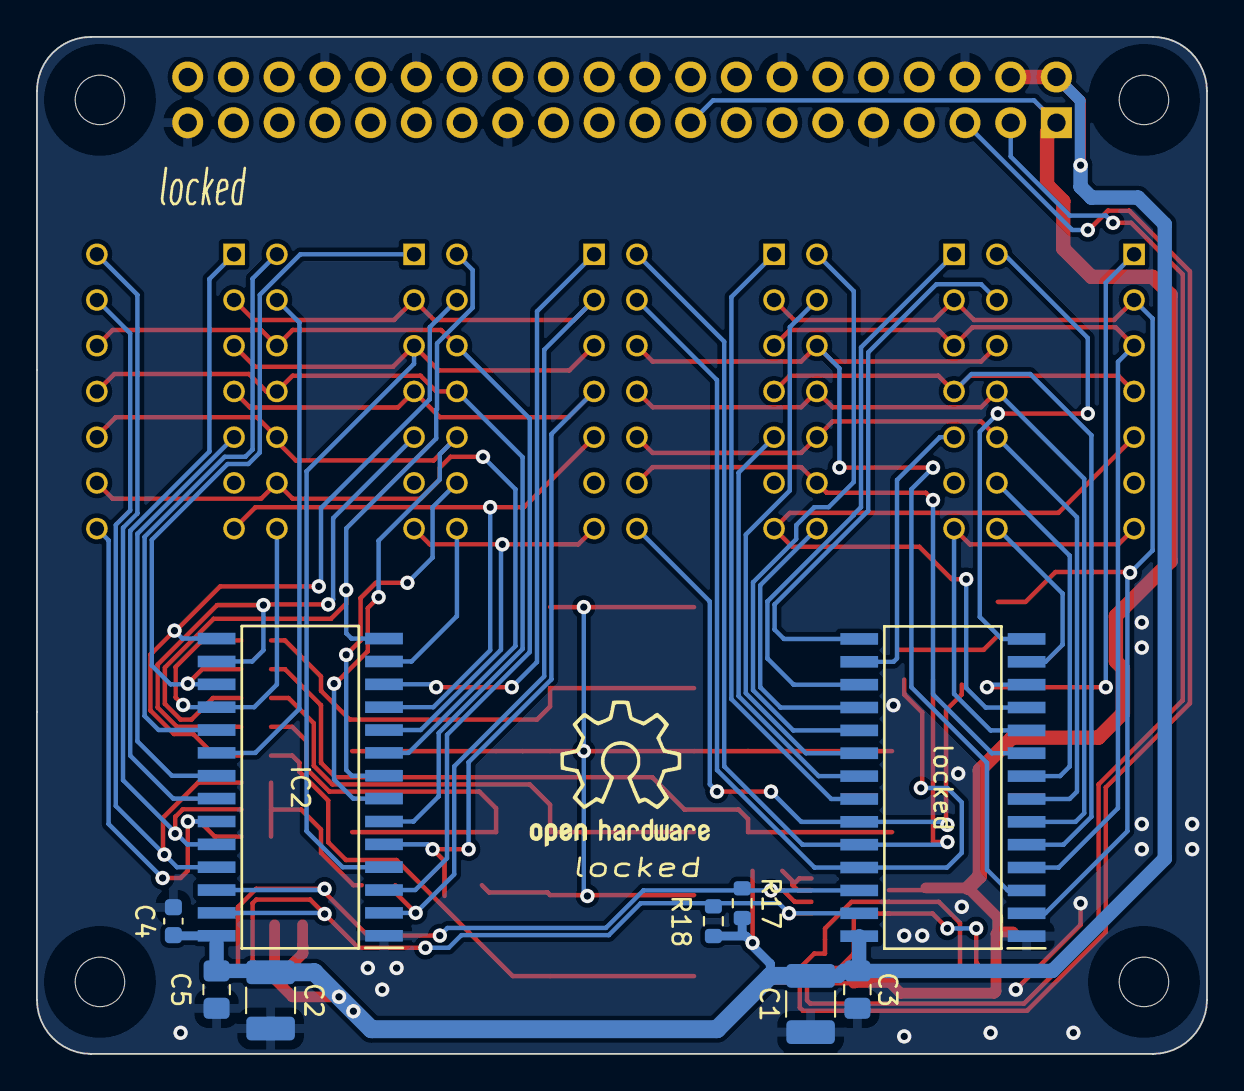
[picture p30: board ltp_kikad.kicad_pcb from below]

Board: 2 copper layers, 65.0 x 56.5 mm, 48 parts (9 on the bottom side), 64 nets.

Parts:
C1, C2, C6, C7: 15uF; C_1210_3225Metric_Pad1.33x2.70mm_HandSolder
C3, C5: 10uF; C_0805_2012Metric_Pad1.18x1.45mm_HandSolder
C4, C9, C10: 10uF; C_0603_1608Metric
C8, C11, C12: 0.1uF; C_0603_1608Metric
D1, D2, D3: 1N4148; D_0805_2012Metric
DS1, DS2, DS3, DS4, DS5, DS6: LTP-305G; DIPS762W50P254L1850H400Q14N
IC2: SamacSys_Parts_HT16K33-28SOP; SOIC127P1031X264-28N
J1: RPi_GPIO; Pin_Header_Straight_2x20
J2, J3: SM04B-SRSS-TB(LF)(SN); JST_SM04B-SRSS-TB(LF)(SN)
R1, R2, R3, R4, R5, R6, R7, R8, R9, R10, R11, R13: 47k; R_0603_1608Metric
R15: 10k; R_0603_1608Metric
R16: 200k; R_0603_1608Metric
R17, R18: i2c; R_0603_1608Metric
SW1, SW2, SW3, SW4, SW5: SW_Omron_B3FS; SW_SPST_Omron_B3FS-105xP
U1: PCA9306DP; TSSOP-8_3x3mm_P0.65mm
locked: SamacSys_Parts_HT16K33-28SOP; SOIC127P1031X264-28N

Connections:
2_an0: DS6.13 (ANODE_COLUMN_5), IC2.25 (ROW0/A2), R9.2
2_an1: DS6.14 (ANODE_COLUMN_4), IC2.24 (ROW1/A1), R10.2
2_an2: DS6.8 (ANODE_COLUMN_3), IC2.23 (ROW2/A0), R11.2
2_an3: DS6.1 (ANODE_COLUMN_2), IC2.22 (ROW3/K1)
2_an4: DS6.5 (ANODE_COLUMN_1), IC2.21 (ROW4/K2)
2_an5: DS5.13 (ANODE_COLUMN_5), IC2.20 (ROW5/K3)
2_an6: DS5.14 (ANODE_COLUMN_4), IC2.19 (ROW6/K4)
2_an7: DS5.8 (ANODE_COLUMN_3), IC2.18 (ROW7/K5), R7.2
2_an8: DS5.1 (ANODE_COLUMN_2), IC2.17 (ROW8/K6), R8.2
2_an9: DS5.5 (ANODE_COLUMN_1), IC2.16 (ROW9/K7), R1.2
2_an10: DS4.13 (ANODE_COLUMN_5), IC2.15 (ROW10/K8), R5.2
2_an11: DS4.14 (ANODE_COLUMN_4), IC2.14 (ROW11/K9), R6.2
2_an12: DS4.8 (ANODE_COLUMN_3), IC2.13 (ROW12/K10)
2_an13: DS4.1 (ANODE_COLUMN_2), IC2.12 (ROW13/K11)
2_an14: DS4.5 (ANODE_COLUMN_1), DS6.7 (ANODE_DECIMAL_POINT), IC2.11 (ROW14/K12)
2_an15: DS4.7 (ANODE_DECIMAL_POINT), DS5.7 (ANODE_DECIMAL_POINT), IC2.10 (ROW15/K13/INT)
2_ca0: D2.2 (A), DS4.2 (CATHODE_ROW_1), DS5.2 (CATHODE_ROW_1), DS6.2 (CATHODE_ROW_1), IC2.2 (COM0/AD)
2_ca1: DS4.12 (CAATHODE_ROW_2), DS5.12 (CAATHODE_ROW_2), DS6.12 (CAATHODE_ROW_2), IC2.3 (COM1/KS0)
2_ca2: DS4.3 (CATHODE_ROW_3), DS5.3 (CATHODE_ROW_3), DS6.3 (CATHODE_ROW_3), IC2.4 (COM2/KS1)
2_ca3: D3.2 (A), DS4.4 (CATHODE_ROW_4), DS5.4 (CATHODE_ROW_4), DS6.4 (CATHODE_ROW_4), IC2.5 (COM3/KS2)
2_ca4: DS4.11 (CATHODE__ROW_5), DS5.11 (CATHODE__ROW_5), DS6.11 (CATHODE__ROW_5), IC2.6 (COM4)
2_ca5: DS4.10 (CATHODE_ROW_6), DS5.10 (CATHODE_ROW_6), DS6.10 (CATHODE_ROW_6), IC2.7 (COM5)
2_ca6: DS4.9 (CATHODE_ROW_7), IC2.8 (COM6)
2_ca7: DS5.9 (CATHODE_ROW_7), DS6.9 (CATHODE_ROW_7), IC2.9 (COM7)
5vSCL: IC2.26 (SCL), J2.4, R17.1, U1.6 (SCL2), locked.26 (SCL)
5vSDA: IC2.27 (SDA), J2.3, R18.1, U1.5 (SDA2), locked.27 (SDA)
+3V3: C6.2, C7.2, C8.2, C9.1, C11.1, J1.1 (3.3V), J1.17 (3.3V), J3.2, R13.2, R15.2, U1.2 (VREF1)
+5V: C1.2, C2.2, C3.1, C4.1, C5.1, C10.1, C12.1, IC2.28 (VDD), J1.2 (5V), J1.4 (5V), J2.2, R16.1, R17.2, R18.2, locked.28 (VDD)
GND: C1.1, C2.1, C3.2, C4.2, C5.2, C6.1, C7.1, C8.1, C9.2, C10.2, C11.2, C12.2, IC2.1 (VSS), J1.6 (GND), J1.9 (GND), J1.14 (GND), J1.20 (GND), J1.25 (GND), J1.30 (GND), J1.34 (GND), J1.39 (GND), J2.1, J2.S1 (SHIELD), J2.S2 (SHIELD), J3.1, J3.S1 (SHIELD), J3.S2 (SHIELD), U1.1 (GND), locked.1 (VSS)
unnamed: D1.1 (K), R2.1, R3.1, R4.1
unnamed: D2.1 (K), R9.1, R10.1, R11.1
unnamed: R1.1, SW1.2
unnamed: R5.1, SW3.2
unnamed: R6.1, SW4.2
unnamed: R7.1, SW2.2
unnamed: R8.1, SW5.2
unnamed: R16.2, U1.7 (VREF2), U1.8 (EN)
SCL: J1.5 (BCM3_SCL), J3.4, R15.1, U1.3 (SCL1)
SDA: J1.3 (BCM2_SDA), J3.3, R13.1, U1.4 (SDA1)
an0: DS3.13 (ANODE_COLUMN_5), R2.2, locked.25 (ROW0/A2)
an1: DS3.14 (ANODE_COLUMN_4), R3.2, locked.24 (ROW1/A1)
an2: DS3.8 (ANODE_COLUMN_3), R4.2, locked.23 (ROW2/A0)
an3: DS3.1 (ANODE_COLUMN_2), locked.22 (ROW3/K1)
an4: DS3.5 (ANODE_COLUMN_1), locked.21 (ROW4/K2)
an5: DS2.13 (ANODE_COLUMN_5), locked.20 (ROW5/K3)
an6: DS2.14 (ANODE_COLUMN_4), locked.19 (ROW6/K4)
an7: DS2.8 (ANODE_COLUMN_3), locked.18 (ROW7/K5)
an8: DS2.1 (ANODE_COLUMN_2), locked.17 (ROW8/K6)
an9: DS2.5 (ANODE_COLUMN_1), locked.16 (ROW9/K7)
an10: DS1.13 (ANODE_COLUMN_5), locked.15 (ROW10/K8)
an11: DS1.14 (ANODE_COLUMN_4), locked.14 (ROW11/K9)
an12: DS1.8 (ANODE_COLUMN_3), locked.13 (ROW12/K10)
an13: DS1.1 (ANODE_COLUMN_2), locked.12 (ROW13/K11)
an14: DS1.5 (ANODE_COLUMN_1), DS3.7 (ANODE_DECIMAL_POINT), locked.11 (ROW14/K12)
an15: DS1.7 (ANODE_DECIMAL_POINT), DS2.7 (ANODE_DECIMAL_POINT), locked.10 (ROW15/K13/INT)
ca0: D1.2 (A), DS1.2 (CATHODE_ROW_1), DS2.2 (CATHODE_ROW_1), DS3.2 (CATHODE_ROW_1), locked.2 (COM0/AD)
ca1: DS1.12 (CAATHODE_ROW_2), DS2.12 (CAATHODE_ROW_2), DS3.12 (CAATHODE_ROW_2), locked.3 (COM1/KS0)
ca2: DS1.3 (CATHODE_ROW_3), DS2.3 (CATHODE_ROW_3), DS3.3 (CATHODE_ROW_3), locked.4 (COM2/KS1)
ca3: DS1.4 (CATHODE_ROW_4), DS2.4 (CATHODE_ROW_4), DS3.4 (CATHODE_ROW_4), locked.5 (COM3/KS2)
ca4: DS1.11 (CATHODE__ROW_5), DS2.11 (CATHODE__ROW_5), DS3.11 (CATHODE__ROW_5), locked.6 (COM4)
ca5: DS1.10 (CATHODE_ROW_6), DS2.10 (CATHODE_ROW_6), DS3.10 (CATHODE_ROW_6), locked.7 (COM5)
ca6: DS1.9 (CATHODE_ROW_7), locked.8 (COM6)
ca7: DS2.9 (CATHODE_ROW_7), DS3.9 (CATHODE_ROW_7), locked.9 (COM7)
sw_ks2: D3.1 (K), SW1.1, SW2.1, SW3.1, SW4.1, SW5.1

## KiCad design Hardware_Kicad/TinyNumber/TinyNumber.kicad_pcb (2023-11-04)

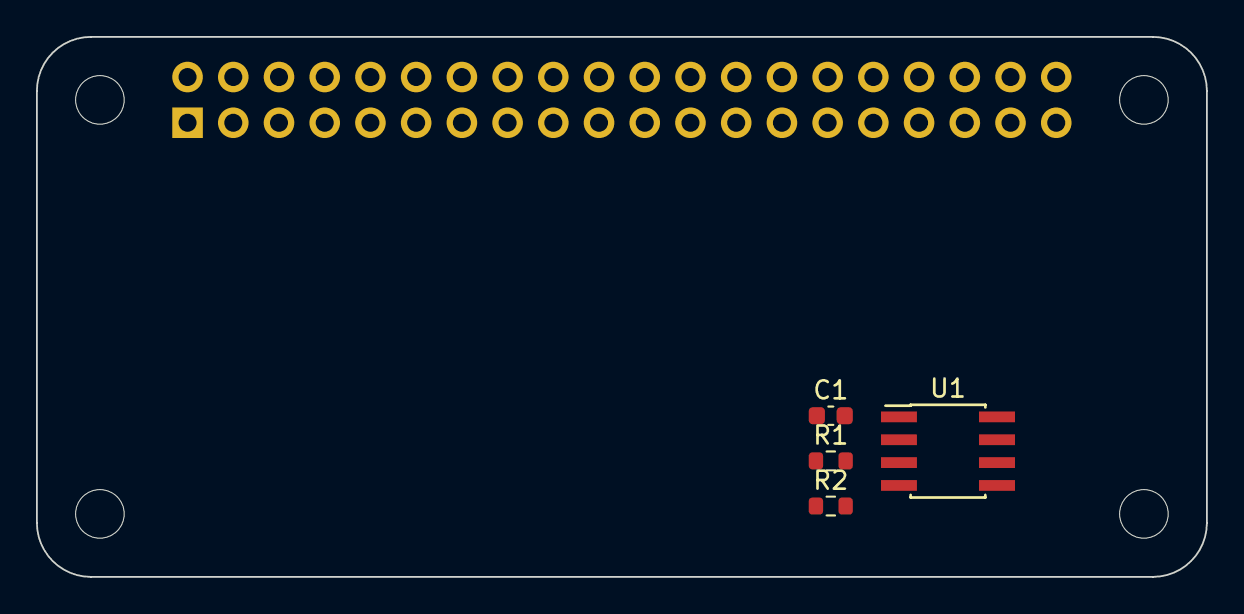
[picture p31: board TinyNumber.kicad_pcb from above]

Board: 2 copper layers, 65.0 x 30.0 mm, 9 parts (1 on the bottom side), 5 nets, no tracks yet.

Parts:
C1: 100n; C_0603_1608Metric
J1: GPIO; PinSocket_2x20_P2.54mm_Vertical
MH1, MH2, MH3, MH4: MountingHole_2.7mm_M2.5
R1, R2: 3.9k; R_0603_1608Metric
U1: CAT24C256; PowerIntegrations_SO-8

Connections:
+3V3: C1.1, J1.1, J1.17, R1.1, R2.1, U1.8 (VCC)
+5V: J1.2, J1.4
/ID_SCL: J1.28, R2.2, U1.6 (SCL)
/ID_SDA: J1.27, R1.2, U1.5 (SDA)
GND: C1.2, J1.6, J1.9, J1.14, J1.20, J1.25, J1.30, J1.34, J1.39, U1.4 (GND)

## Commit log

2023-07-13 Add 3d device render
    [ltp_kikad.kicad_pcb]
2023-07-18 Minimize vias transitions, optimize traces
    [ltp_kikad.kicad_pcb]
2023-07-24 Minor improvements
    [ltp_kikad.kicad_pcb]
2023-07-24 Add bypas cap
    [ltp_kikad.kicad_pcb, ltp_kikad.kicad_sch]
2023-07-25 Optimize connection routes
    [ltp_kikad.kicad_pcb]
2023-07-25 Shorten some routes
    [ltp_kikad.kicad_pcb]
2023-07-25 Minor fixes
    [ltp_kikad.kicad_pcb]
2023-07-26 Add qwiic stemma i2c connector
    [ltp_kikad-B_Cu.gbl, ltp_kikad-B_Mask.gbs, ltp_kikad-B_Paste.gbp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]
2023-07-27 Optimize design, add bypass caps
    [ltp_kikad.kicad_pcb, ltp_kikad.kicad_sch]
2023-07-27 Optimize filled zones
    [ltp_kikad.kicad_pcb]
2023-07-27 Optimize filled zones, minimize clearence, reroute some led traces
    [ltp_kikad.kicad_pcb]
2023-07-27 Miscellaneous optimisation
    [ltp_kikad.kicad_pcb, ltp_kikad.kicad_sch]
2023-07-27 V 0.01
    [ltp_kikad.kicad_pcb]
2023-07-27 Add product name, minor fixes
    [ltp_kikad-B_Cu.gbl, ltp_kikad-B_Mask.gbs, ltp_kikad-B_Paste.gbp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]
2023-07-27 Fix 40 pin footprint, bump version to 0.01a
    [ltp_kikad-B_Cu.gbl, ltp_kikad-B_Mask.gbs, ltp_kikad-B_Paste.gbp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]
2023-07-28 Changes to 0.01a
    [ltp_kikad.kicad_pcb]
2023-07-29 Version 0.02
    [ltp_kikad.kicad_pcb]
2023-07-29 Updates to 0.02
    [ltp_kikad.kicad_pcb]
2023-07-29 Updates to 0.03
    [ltp_kikad.kicad_pcb, ltp_kikad.kicad_sch]
2023-07-29 Minor Updates to 0.03
    [ltp_kikad.kicad_pcb]
2023-07-29 Add artwork and logo
    [ltp_kikad.kicad_pcb]
2023-07-30 V 0.04a 0Add CAN tranciver, set 3d models for components
    [led_drivers.kicad_sch, ltp_kikad.kicad_pcb, ltp_kikad.kicad_sch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]
2023-07-31 Add PCA9306 i2c transciever
    [i2c_transceiver.kicad_sch, ltp_kikad.kicad_pcb, ltp_kikad.kicad_sch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]
2023-07-31 Update placement, Gerade device 3d model
    [i2c_transceiver.kicad_sch, ltp_kikad.kicad_pcb]
2023-08-01 Version 0.05
    [i2c_connector.kicad_sch, i2c_transceiver.kicad_sch, ltp_kikad.kicad_pcb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]
2023-08-01 Add testpoints
    [i2c_connector.kicad_sch, i2c_transceiver.kicad_sch, led_drivers.kicad_sch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]
2023-08-02 Minimize distances between displays
    [ltp_kikad.kicad_pcb]
2023-08-02 Fix routes
    [ltp_kikad.kicad_pcb]
2023-08-03 Version 0.06
    [ltp_kikad.kicad_pcb, ltp_kikad.kicad_sch]
2023-08-03 Updates vias
    [ltp_kikad.kicad_pcb]
2023-08-05 Add rp2040 mcu, remove mcp2515
    [i2c_transceiver.kicad_sch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]
2023-08-06 Use 402 footprint for rp2040 mcu part
    [i2c_transceiver.kicad_sch, ltp_kikad.kicad_pcb, ltp_kikad.kicad_sch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]
2023-08-07 Update design
    [ltp_kikad.kicad_pcb]
2023-08-07 Update update drc, move spi flash
    [ltp_kikad.kicad_pcb]
2023-08-07 Update design place rgb led
    [ltp_kikad.kicad_pcb, mcu.kicad_sch]
2023-08-08 Add user buttons
    [ltp_kikad.kicad_pcb, mcu.kicad_sch]
2023-08-08 Reroute i2c, connect user buttons
    [ltp_kikad.kicad_pcb, mcu.kicad_sch]
2023-08-10 Add mcp 2517 can transceiver
    [can.kicad_sch, i2c_connector.kicad_sch, i2c_transceiver.kicad_sch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]
2023-08-11 move to 4 layers
    [can.kicad_sch, ltp_kikad.kicad_pcb, mcu.kicad_sch]
2023-08-11 Update routes
    [ltp_kikad.kicad_pcb]
2023-08-11 Add CAN TVS protection
    [can.kicad_sch, ltp_kikad.kicad_pcb]
2023-08-11 Add CAN TVS routes
    [ltp_kikad.kicad_pcb]
2023-08-12 Add CAN stby
    [can.kicad_sch, ltp_kikad.kicad_pcb, mcu.kicad_sch]
2023-08-13 Fix can stby jumper
    [can.kicad_sch, ltp_kikad.kicad_pcb]
2023-08-14 Move power traces, to iner layer, fix some drc violations
    [ltp_kikad.kicad_pcb]
2023-08-14 Updates 2
    [i2c_transceiver.kicad_sch, ltp_kikad.kicad_pcb]
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2023-08-17 Verssion updates to 0.11
    [ltp_kikad.kicad_pcb]
2023-08-17 Updates, more estetic routes, change silkscreen font
    [ltp_kikad.kicad_pcb]
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2023-08-29 Update crystal footprint, move i2c lines to iner layer
    [i2c_connector.kicad_sch, ltp_kikad.kicad_pcb, mcu.kicad_sch]
2023-09-14 Fix connection on an6 an5 ds2
    [ltp_kikad.kicad_sch]
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2023-09-30 Fix connections
    [i2c_connector.kicad_sch, led_drivers.kicad_sch, ltp_kikad.kicad_pcb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]
2023-09-30 Add 6mm omron tactile switches
    [led_drivers.kicad_sch, ltp_kikad.kicad_pcb]
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2023-10-01 Connect decimal points ds3 ds5, add cap
    [i2c_connector.kicad_sch, led_drivers.kicad_sch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]
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2023-10-05 3D models path for pcd viewer
    [ltp_kikad.kicad_pcb]
2023-10-05 Update silk screen values
    [ltp_kikad.kicad_pcb]
2023-10-05 Set ltp 305 3d model path
    [ltp_kikad.kicad_pcb]
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2023-10-05 Optimise routes, add caps
    [i2c_connector.kicad_sch, ltp_kikad.kicad_pcb]
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2023-10-14 Add dc-dc 3.3v to 5v
    [dcdc.kicad_sch, i2c_connector.kicad_sch, led_drivers.kicad_sch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]
2023-10-14 Add i2c transciever, Pitanga V2
    [i2c_tramsciever.kicad_sch, led_drivers.kicad_sch, ltp_kikad.kicad_pcb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]
2023-10-15 Add Pitanga V2 gerbers
    [ltp_kikad-B_Cu.gbl, ltp_kikad-B_Mask.gbs, ltp_kikad-B_Paste.gbp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]
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2023-10-19 Fix decimal point connection on ds4, add info to title block
    [dcdc.kicad_sch, i2c_connector.kicad_sch, i2c_tramsciever.kicad_sch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]
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2023-10-21 Mutimplex cat6 and cat7 conect decimal point on second diplay module
    [led_displays.kicad_sch, led_drivers.kicad_sch, ltp_kikad.kicad_sch]
2023-10-21 Add second decimal connection to first led driver
    [led_displays.kicad_sch, led_drivers.kicad_sch, ltp_kikad.kicad_pcb]
2023-10-21 Remove isolated gnd areas
    [ltp_kikad.kicad_pcb]
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2023-10-21 Realease v2.1 with 6mm buttons
    [ltp_kikad-B_Cu.gbl, ltp_kikad-B_Mask.gbs, ltp_kikad-B_Paste.gbp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]
2023-11-05 Move from 4 layer to 2, complete roting, separate 5v for led driver and 3v i2c power
    [i2c_connector.kicad_sch, i2c_tramsciever.kicad_sch, led_displays.kicad_sch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]
2023-11-06 Veryfy, connection, label. i2c connectors
    [ltp_kikad.kicad_pcb]
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2023-11-07 Create gerbers for 2.1a
    [ltp_kikad-B_Cu.gbl, ltp_kikad-B_Mask.gbs, ltp_kikad-B_Paste.gbp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]
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
